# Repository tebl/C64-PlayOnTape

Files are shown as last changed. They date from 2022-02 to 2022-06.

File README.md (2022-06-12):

# C64 PlayOnTape
Remember waiting around for what sometimes would feel like forever, just to get your favourite game loaded from your trusty datasette? Well, now you can now attempt to return to a slightly less irritating version of those good old days - loading games'll take just as long as they did back then, just without the need to fiddle with the azimuth setting. Based on the rather excellent [tapuino](https://github.com/sweetlilmre/tapuino) project, there's even an accompanying [blog](http://sweetlilmre.blogspot.com/search/label/Tapuino) that included instructions on how to build one all by yourself.

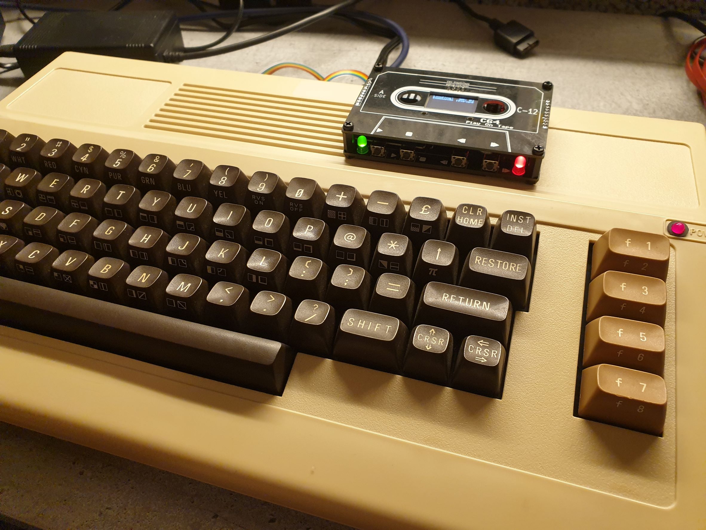
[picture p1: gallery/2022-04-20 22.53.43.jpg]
Finished unit with C64


Personally I haven't had much success building prototypes on breadboards, veroboard and almost every other option available within my severely limited cashflow. I highly suspect that part of this is due to my tendency for only buying the cheapest stuff around, so in order to keep myself sane I went straight from the blog onto designing the PCBs in KiCAD. On the plus side the files are here for anyone to enjoy, just remember that there's no warranty beyond my promise that it worked that one time I built one. If your C64 blows up due to problems assembling or using it, know that I'll be happy to take it off your hands for spare parts.

- [C64 PlayOnTape](#c64-playontape)
  - [1.1> Modules](#11-modules)
  - [1.2> Acknowledgements](#12-acknowledgements)

## 1.1> Modules
For the technical details as well as information regarding the modules included by this specific github project, consult the table below. Follow the documentation links for build instructions, BOM and anything else you'd for that specific module. Faceplates and any backplates listed are for the most most part only decorative, allowing you to put together something similar to a case without actually requiring a 3d-printer. Also, check out the [schematics](https://github.com/tebl/C64-PlayOnTape/tree/main/documentation/schematic) for more information about the electronic side of things.

| Module | Required | Documentation | Order |
| --- | --- | --- | --- |
| [C64 PlayOnTape Module](https://github.com/tebl/C64-PlayOnTape/tree/main/PlayOnTape%20Module) | Yes | [Documentation](https://github.com/tebl/C64-PlayOnTape/blob/main/PlayOnTape%20Module/README.md), [BOM](https://github.com/tebl/C64-PlayOnTape/blob/main/PlayOnTape%20Module/README.md#3-bom), [Getting started](https://github.com/tebl/C64-PlayOnTape/blob/main/documentation/getting_started.md) | [PCBWay](https://www.pcbway.com/project/shareproject/C64_PlayOnTape_7281e4c0.html)
| [C64 PlayOnTape Adapter](https://github.com/tebl/C64-PlayOnTape/tree/main/PlayOnTape%20Adapter) | Yes | [Documentation](https://github.com/tebl/C64-PlayOnTape/blob/main/PlayOnTape%20Adapter/README.md), [BOM](https://github.com/tebl/C64-PlayOnTape/blob/main/PlayOnTape%20Adapter/README.md#3-bom) | [PCBWay](https://www.pcbway.com/project/shareproject/C64_PlayOnTape_Adapter_6b7e3197.html)
| [PlayOnTape Backplate](https://github.com/tebl/C64-PlayOnTape/tree/main/faceplates/PlayOnTape%20Backplate) | No | [Documentation](https://github.com/tebl/C64-PlayOnTape/blob/main/faceplates/PlayOnTape%20Backplate/README.md) | [PCBWay](https://www.pcbway.com/project/shareproject/C64_PlayOnTape_Backplate_04d028fa.html)
| [PlayOnTape Faceplate (A1)](https://github.com/tebl/C64-PlayOnTape/tree/main/faceplates/PlayOnTape%20Faceplate%20A1) | Recommended | [Documentation](https://github.com/tebl/C64-PlayOnTape/blob/main/faceplates/PlayOnTape%20Faceplate%20A1/README.md), [BOM](https://github.com/tebl/C64-PlayOnTape/blob/main/faceplates/PlayOnTape%20Faceplate%20A1/README.md#3-bom) | [PCBWay](https://www.pcbway.com/project/shareproject/C64_PlayOnTape_Faceplate_FA1_dac67ded.html)

## 1.2> Acknowledgements
Everything comes from something, in particular when it comes to most of my electronics projects. I mainly build things I would like to own, often doing a respin to fit my own particular style and preferences with most of the hardest parts of the designs already provided by people more knowledgable than I. As already mentioned, my designs are based on the rather excellent [tapuino](https://github.com/sweetlilmre/tapuino) project with a new name just to keep things separate, for more details on how it functions - check out his accompanying [blog](http://sweetlilmre.blogspot.com/search/label/Tapuino) as well.

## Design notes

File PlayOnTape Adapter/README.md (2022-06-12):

# PlayOnTape Adapter
Originally I designed the [C64 PlayOnTape](https://github.com/tebl/C64-PlayOnTape) with the idea that I would simply solder the cable straight to a connector and call it a day, but then I remembered that I've always loathed soldering cables thought that might be a case of having both too many and too few thumbs depending on the situation. The following revision was therefore redesigned with this little adapter board, so that the two can be connected using a commonly sold 2x3 pin IDC flat ribbon cable (usually sold as a *"6pin IDC JTAG ISP"*-cable on ebay and similar sites).

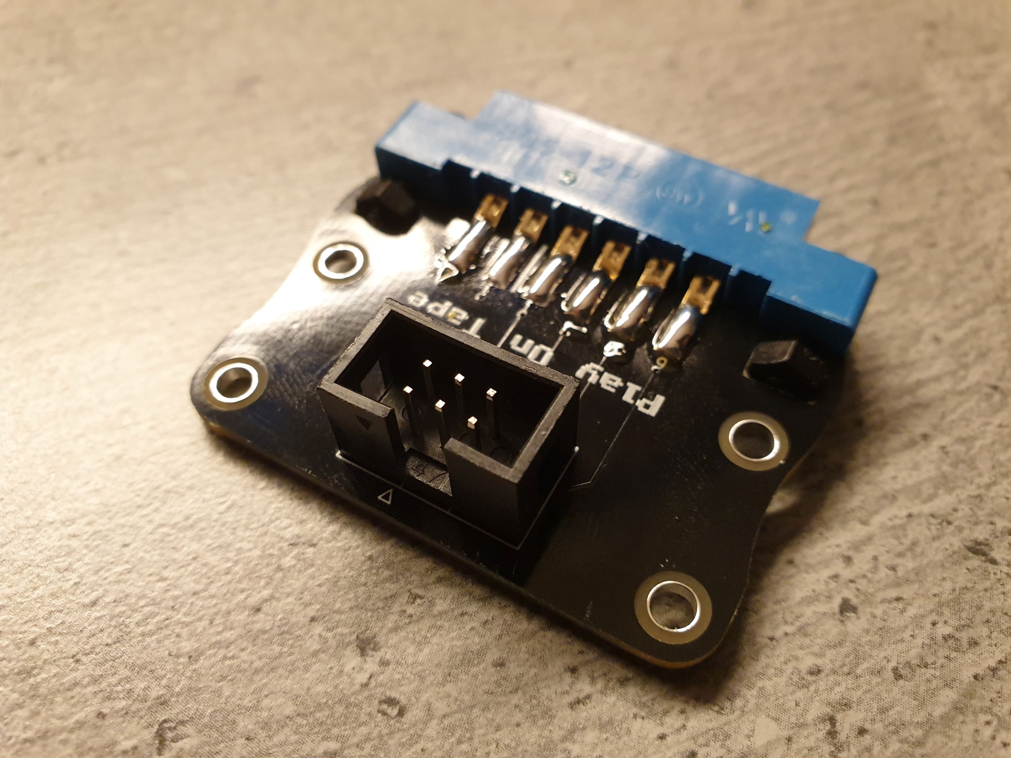
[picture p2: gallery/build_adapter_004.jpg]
Completed unit


- [PlayOnTape Adapter](#playontape-adapter)
  - [1> Building the module](#1-building-the-module)
  - [2> Schematic](#2-schematic)
  - [3> BOM](#3-bom)

## 1> Building the module
Start by checking out the [BOM](#3-bom) and verify that you have the components needed before continuing, it's beyond frustrating to realize you need just that single item before being able to complete the build - with shipping times from China being what they are, it's better to get it right the first time. Personally I find that if it's very cheap, I'll just order several different ones - just in case one gets delayed or lost somewhere.

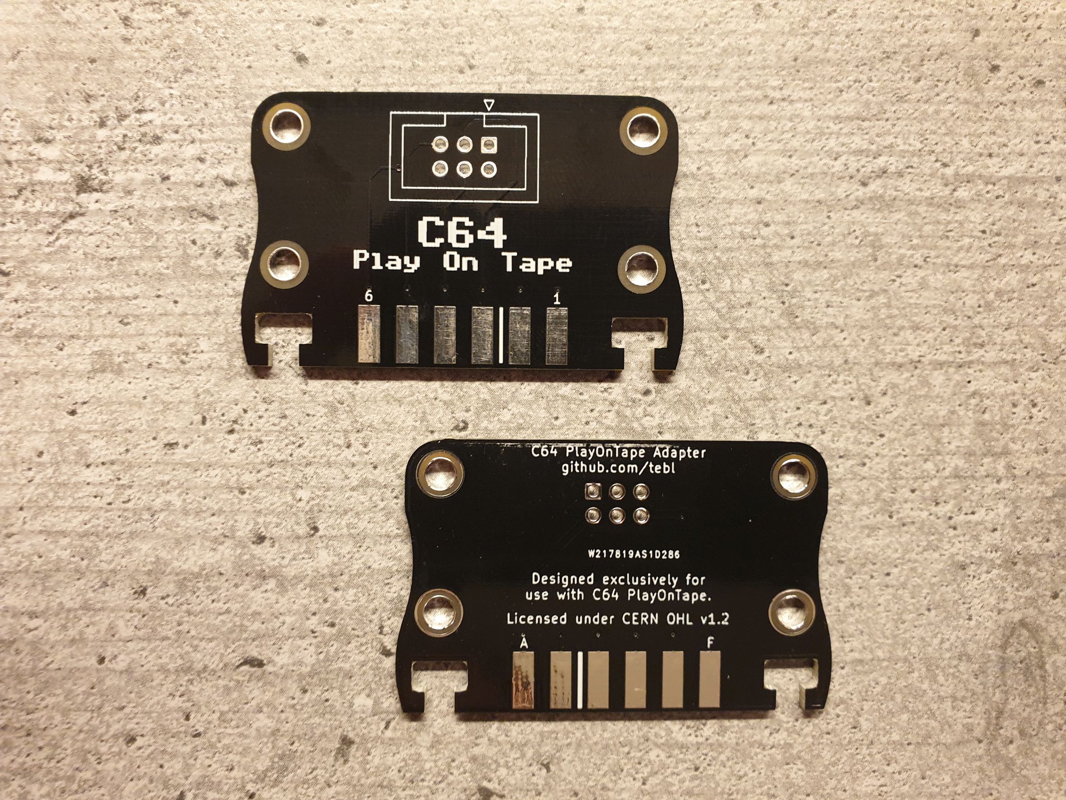
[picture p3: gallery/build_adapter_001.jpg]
Build 001


Starting by doing a visual inspection of the PCB, familiarize yourself with the placement of components as ordered - in particular, which side of the board that the components themselves should be soldered. Towards the sides there is a slot for holding a couple of M3-nuts, this is used to keep the connector from breaking away due to handling.

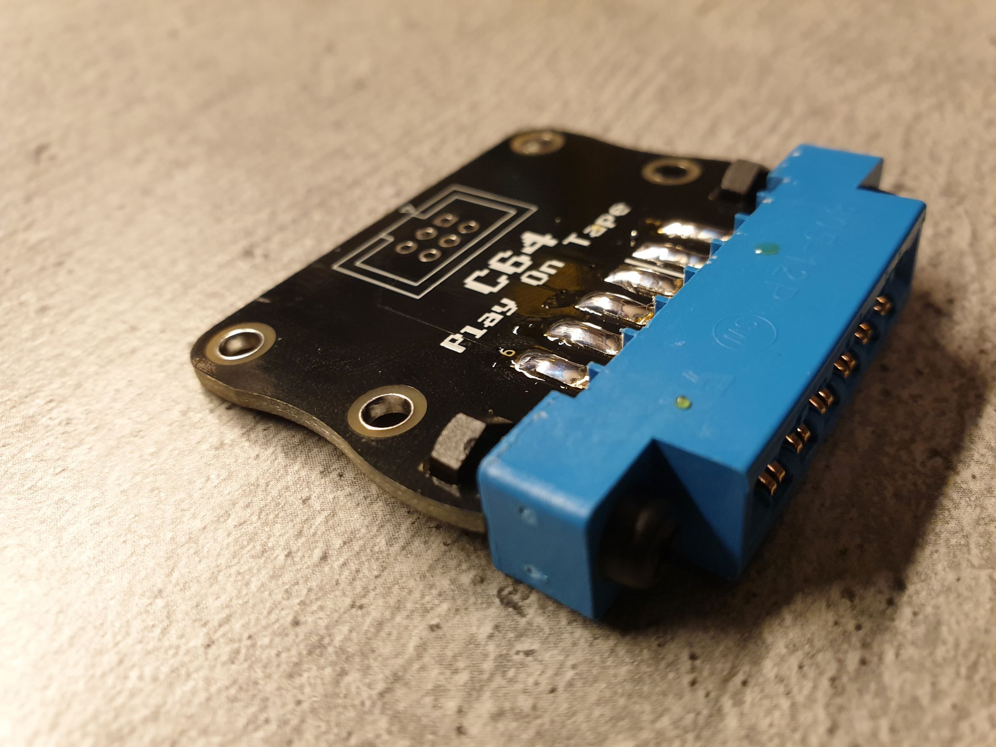
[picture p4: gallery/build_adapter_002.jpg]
Build 002


The 805-series connector comes in two variants, one with wider contacts that can have wires soldered to them and the more narrow pins intended for inserting into and soldering onto a PCB. We're - almost - not doing any of that, so either variant will be fine. Instead we will be soldering it an angle onto the side of the PCB as shown above, but since we want it to be a somewhat mechanically good connection we'll start by attaching it using the nylon M3-nuts and screws. The nuts'll only fit in the way that is shown, for the screws we'll just screw it through the connector and into the nut (cutting down the length of the screws as needed).

When the screws are fitted into place, it should hold the connector well enough that we can look into soldering it into place. At this point you'll usually have the pins hovering somewhat over the PCB, this is easily rectified by using the flat edge of a screwdriver to push each of them at angle so that they align with the pads below. Then, we just solder each of the pins into place, using plenty of solder to give it some added support.

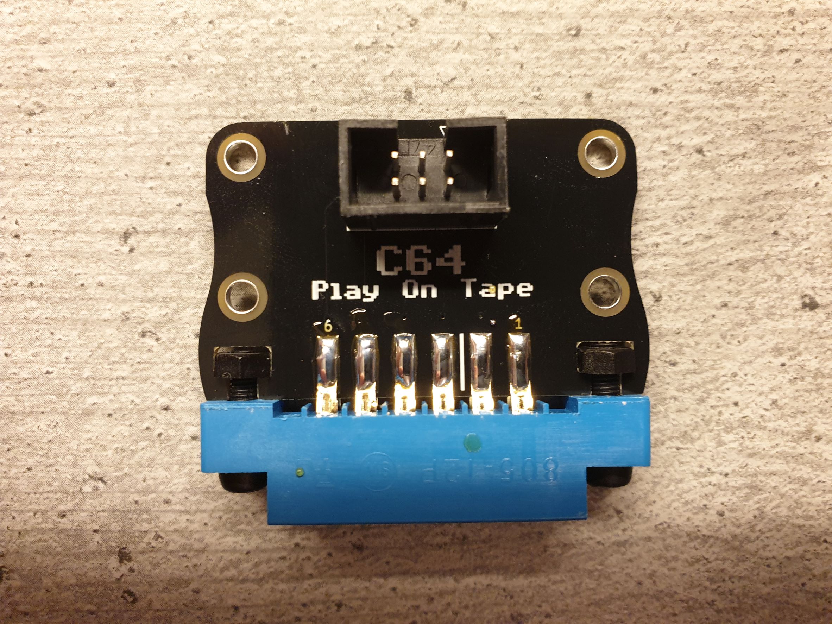
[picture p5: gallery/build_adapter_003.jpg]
Build 002


The last part is just adding the 2x3 pin IDC male straight socket, ensuring that the keying ends up in the correct orientation. At the bottom between some of the 805-series connector pins there is also a white line, this should match the keying one would expect to be used with the Commodore 64s cassette port. I don't think there's anything sold that would work, but you can easily make it from a piece of plastic by following a video by [Hey Birt!](https://www.youtube.com/c/HeyBirt) on the topic of [stupid proofing your edge connectors](https://www.youtube.com/watch?v=vWt5WGZH8hI).

# 2> Schematic
The supplied KiCad files should be sufficient as both a schematic and as a  starting point for ordering PCBs (basically you could just zip the contents of the export folder and upload that on a fabrication site), the schematic is also available in [PDF-format](https://github.com/tebl/C64-PlayOnTape/tree/main/documentation/schematic) found within the schematics-part of the [documentation](https://github.com/tebl/C64-PlayOnTape/tree/main/documentation).

# 3> BOM
Most parts should be easy to get a hold of from your favourite local electronic component shop, but given that I don't have access to such shops where I live so everything was based on whatever I could get cheapest from eBay/AliExpress (free shipping, plan on waiting 3-4 weeks for delivery though). If you are in doubt what to order from a high-end electronics parts provider, I recommend that you study the pictures as the more common Chinese parts may be harder to find in the myriad of options presented there.

| Reference | Item | Count | Order |
| --- | --- | ----- | ----- |
| PCB | Fabricate using Gerber files | 1 | [PCBWay](https://www.pcbway.com/project/shareproject/C64_PlayOnTape_Adapter_6b7e3197.html)
| J1 * | 2x3 pin straight male IDC-socket | 1 |
| J2 | 12-pin 805-series 3.96mm card edge connector | 1 |
| Cable | 6-pin IDC cable | 1 |

*) This could be replaced by standard male pin headers if you wanted to, but using the keyed IDC-connector is recommended in order to avoid accidents.

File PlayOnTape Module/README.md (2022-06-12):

# PlayOnTape Module
Remember waiting around for what sometimes would feel like forever, just to get your favourite game loaded from your trusty datasette? Well, now you can now attempt to return to a slightly less irritating version of those good old days - loading games'll take just as long as they did back then, just without the need to fiddle with the azimuth setting. Based on the rather excellent [tapuino](https://github.com/sweetlilmre/tapuino) project, there's even an accompanying [blog](http://sweetlilmre.blogspot.com/search/label/Tapuino) that included instructions on how to build one all by yourself.

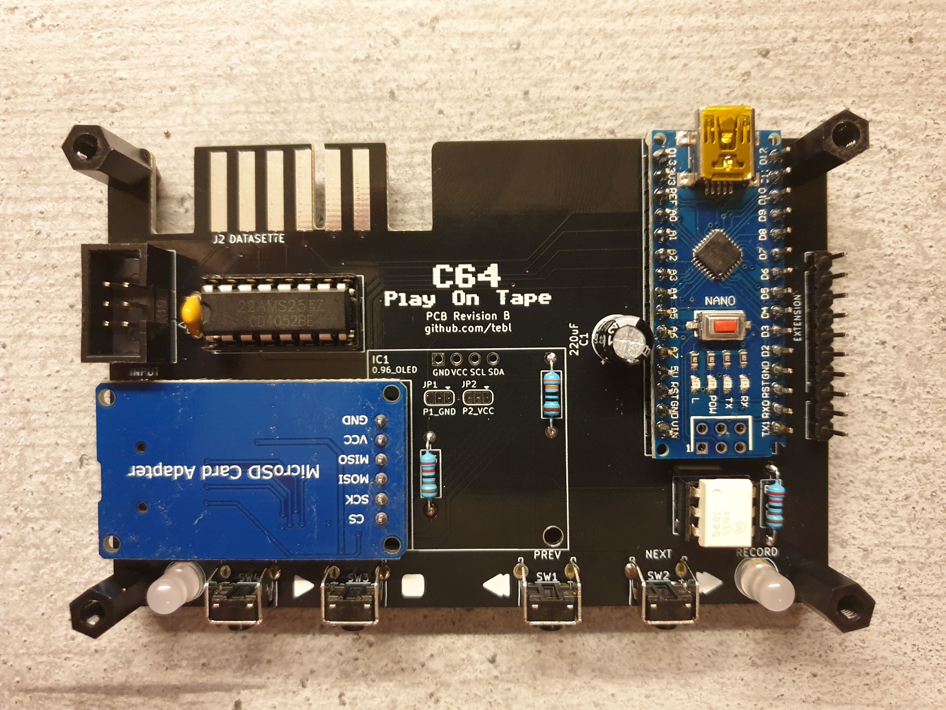
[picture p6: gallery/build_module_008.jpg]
Completed unit


This is the main module, containing most if not all of the electronic circuit needed to make it all work as expected. By most, I mean that even though you can install the display directly on this module in order to build a minimal option, I would expect you to install the display on one of the [faceplates](https://github.com/tebl/C64-PlayOnTape/tree/main/faceplates). You will also need the [cable adapter](https://github.com/tebl/C64-PlayOnTape/tree/main/PlayOnTape%20Adapter) so that you have some way of connecting it to your Commodore 64, via a 6-pin IDC-cable.

- [PlayOnTape Module](#playontape-module)
  - [1> Building the module](#1-building-the-module)
    - [1.1> Installing the display](#11-installing-the-display) 
    - [1.2> Installing the firmware](#12-installing-the-firmware)
    - [1.3> Finishing steps](#13-finishing-steps)
  - [2> Schematic](#2-schematic)
  - [3> BOM](#3-bom)

# 1> Building the module
Start by checking out the [BOM](#3-bom) and verify that you have the components needed before continuing, it's beyond frustrating to realize you need just that single item before being able to complete the build - with shipping times from China being what they are, it's better to get it right the first time. Personally I find that if it's very cheap, I'll just order several different ones - just in case one gets delayed or lost somewhere.

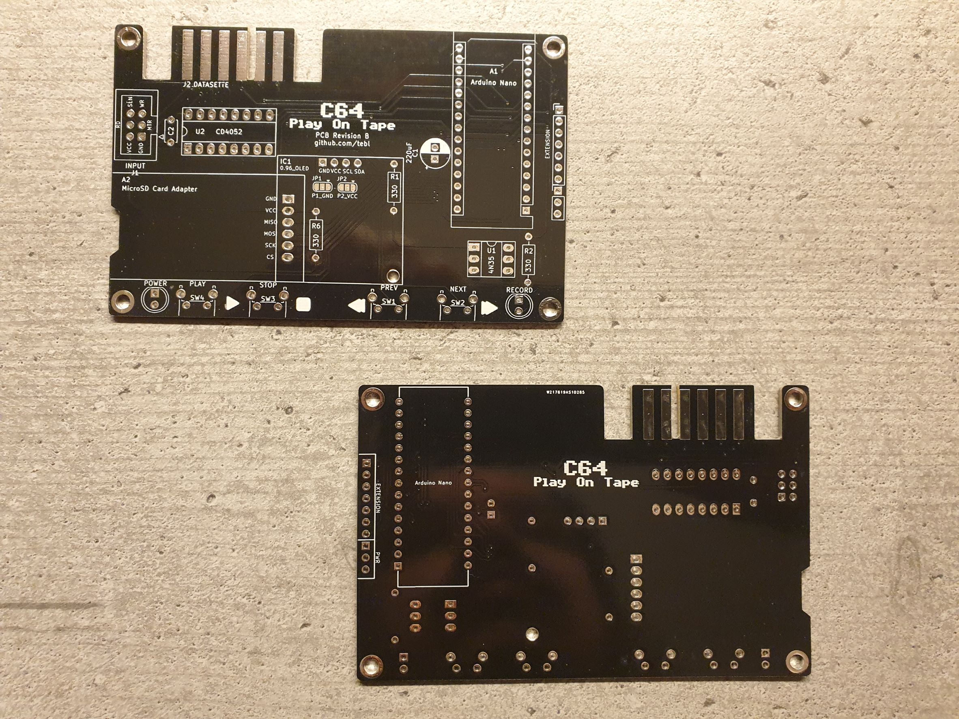
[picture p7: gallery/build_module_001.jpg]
Build 001


Starting by doing a visual inspection of the PCB, familiarize yourself with the placement of components as ordered some time ago. This time, focusing in particular on determining on which side of the board that the components themselves should be soldered and their respective orientation.

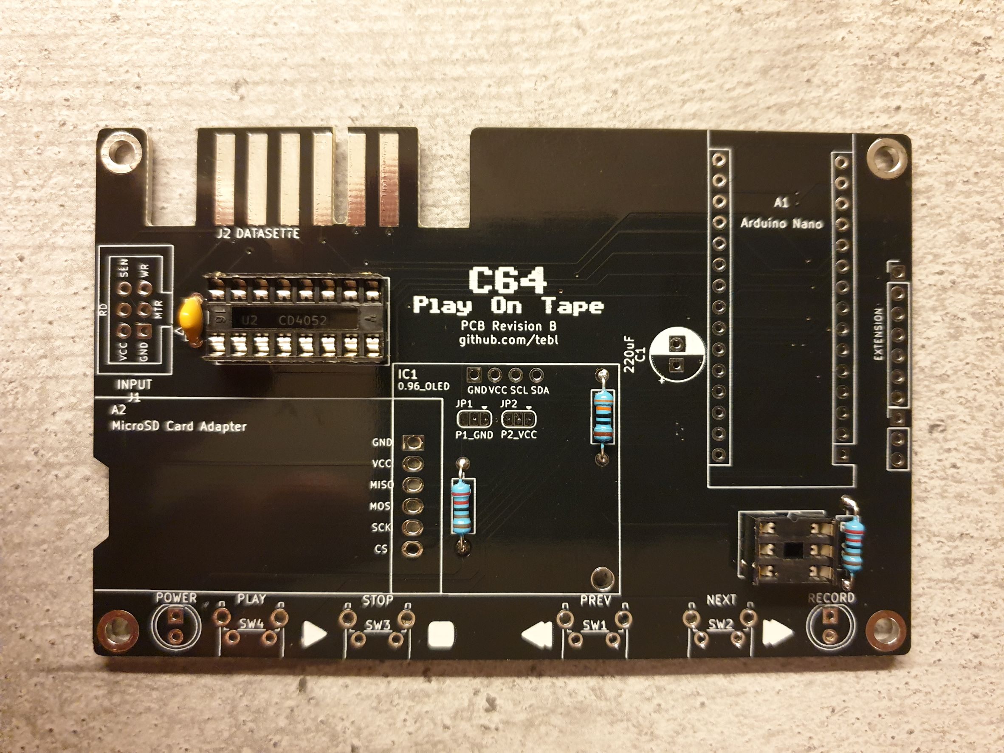
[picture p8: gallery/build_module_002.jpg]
Build 002


As with all builds of this type we'll start by installing the smallest components first, usually going by the height of the components when sitting flush against the board. A good starting point will therefore be the three resistors, but because things are never all that easy - we'll need to pick a potentially more suitable value for R2 and R6. The reason for this is that the value needed would depend on the type of LEDs you are using, the common cheap coloured LEDs will work with this value as long as you resist the temptation to pick *blue* as any of the colours.

The more modern bright or even just clear LEDs have a significantly higher efficiency, meaning that they would likely burn out or simply remain uncomfortably bright at such a low resistor value! The textbook way of handling this kind of issue is reading the datasheet for your LEDs, noting down forward voltage drop and then calculating the proper value to use. Yeah, I'm not doing that either! Your other options are therefore to simply choose a safe value somewhere between 1k and 3k3 (depending on your preferences), try it out on a breadboard or hold off on this until the rest of the unit has been built up and can be powered. If you chose the latter, then you'd just carefully take aim and jam a resistor in there, hold it into place and see if it looks good to you.

Adding the single non-polarized capacitor is the next likely candidate, as a 100nF capacitor it would normally have the number *"104"* printed on it. I've also taken the time to install any sockets needed, mostly because they are cheap and it allows me to easily ~~steal~~ borrow the ICs for some later project - just make sure to line up the little indent marking the side with pin 1 so that it matches what is printed on the PCB itself.

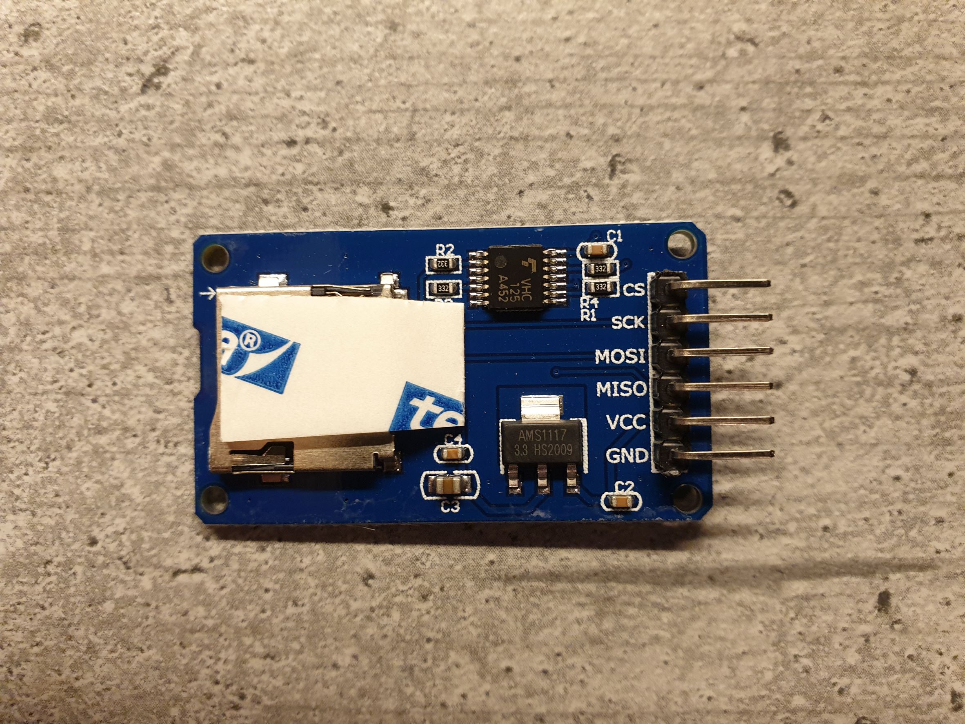
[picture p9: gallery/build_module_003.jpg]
Build 003

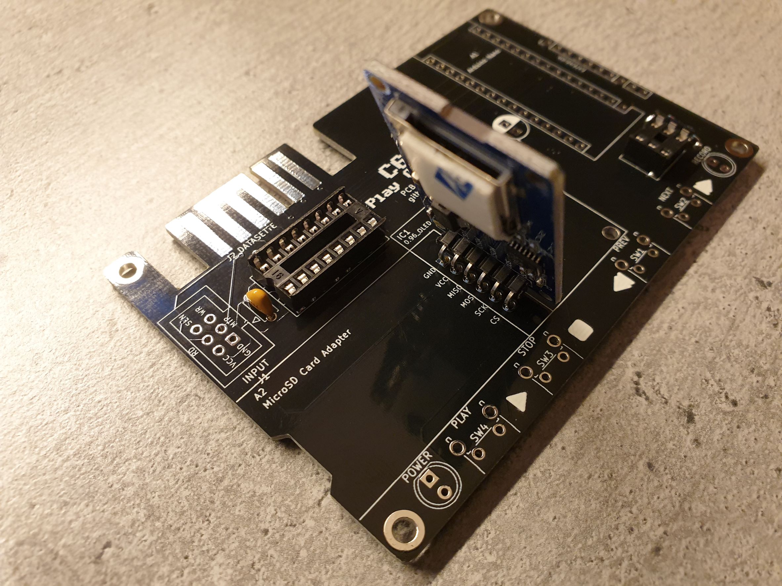
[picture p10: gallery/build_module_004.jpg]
Build 004

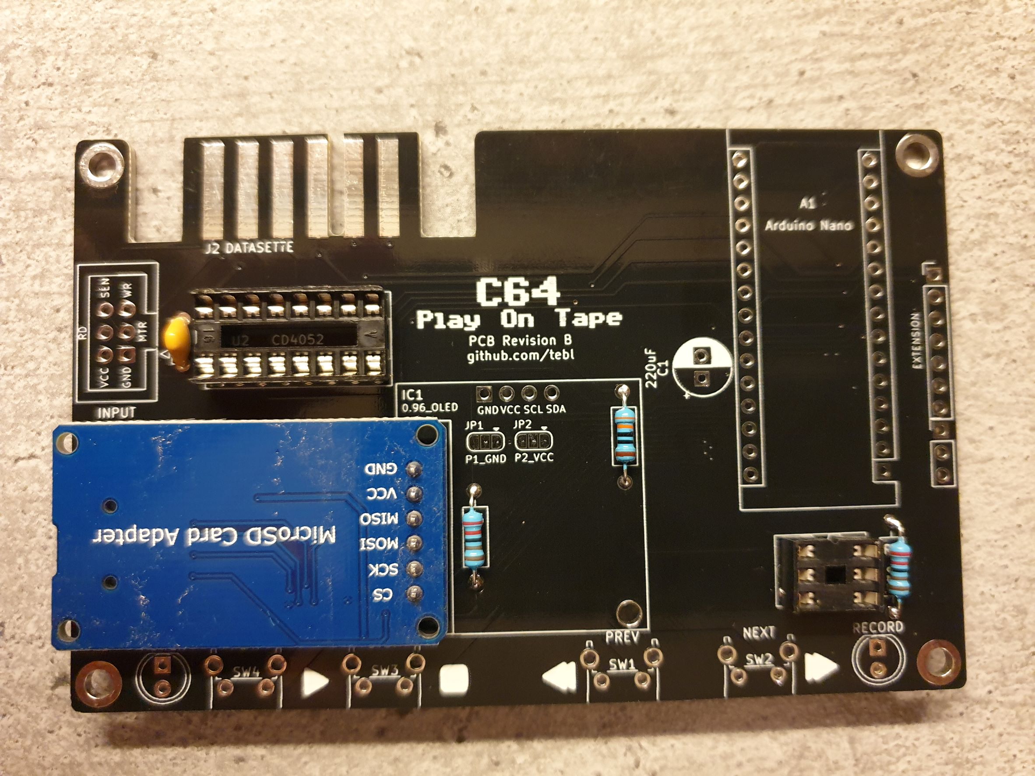
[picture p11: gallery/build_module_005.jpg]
Build 005


Installing the *MicroSD Card Adapter* is easy as long as a few easy steps are followed, mostly just as shown in the images above. First we'll attach a bit of thick double-sided tape, often referenced to as mounting tape, to the top of the adapter MicroSD slot on the adapter. Just take care to leave enough room so that it does not cover up the little latches on the sides of the metal slot. When satisfied insert the pins into the holes, remove the backing on the tape and bend the module over so it ends up sitting flush against the board. Finish up by soldering the pins from the underside, then using trim the excess of the pins using a sturdy set of side-cutting pliers. Touch up the solder points afterwards, just to ensure that we didn't crack any of the joints when doing the cutting.

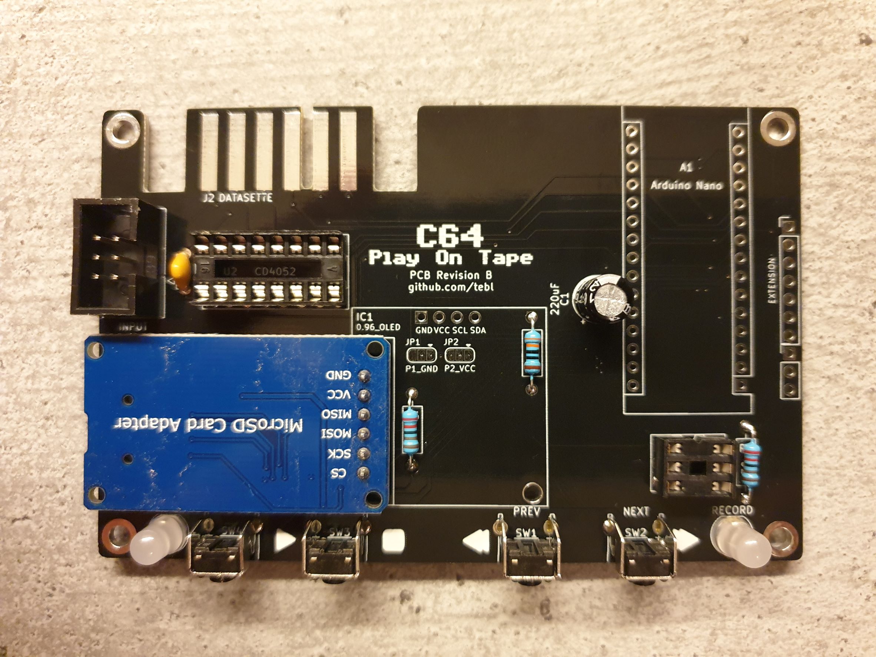
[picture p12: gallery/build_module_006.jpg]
Build 006


Continuing on with the build process, we've added the 6-pin male straight IDC-connector - ensuring that we get the keying in the correct place - followed by adding the switches need to control the device. The LEDs we've already mentioned earlier, but here we've finally gotten to the point of actually installing them - ensuring that the longer pin goes into the round hole.

The board also features a single electrolytic capacitor that we should probably find a place for, this component has a polarity that we need to pay attention to. The line on the component needs to be matched up with the filled in area on the footprint, this will also match up the longer leg with the side marked with a tiny *"+"*. While the circuit doesn't require a specific voltage rating, I recommend using a 16v component as the higher rated parts will be physically larger and taller (causing problems with fitting it under the faceplate). 

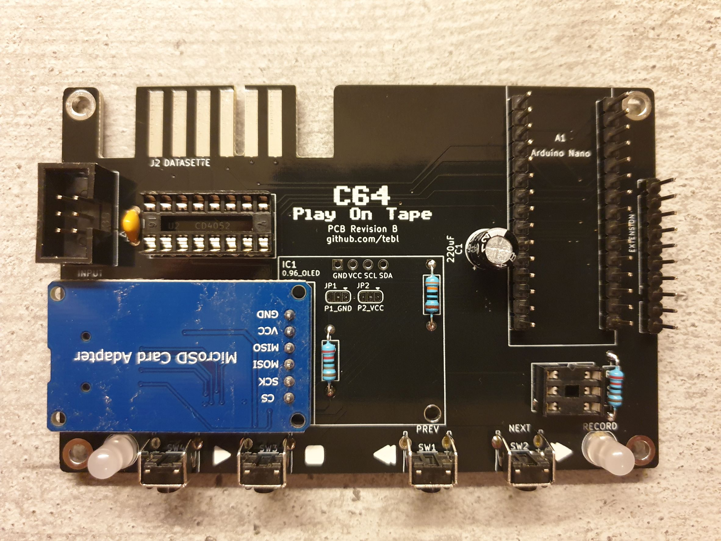
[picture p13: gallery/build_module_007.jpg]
Build 007


The Arduino Nano is attached to the board using standard male pin-headers, these need to be soldered in somewhat straight - or - you may encounter soldering in the Arduino itself. The pin headers on the far-right have also been added, these are used to connect the signals required by the faceplate. 

**NB!** If you have a relatively high expectation in regards to the quality of your components, then there is the option of constructing a device that is slightly thinner. The process is simply to install 8mm hex standoffs, trimming the tops of the Arduino pins, then soldering the longer variety of the pin headers for the right-most pins directly to the faceplate instead of making it detachable (you may need to use longer pin headers or a small section of ribbon cable). Understandably enough, you'd hold off on doing this until every other component has been fitted.

Build 008

The Arduino is then inserted onto the pins, then soldered into place though experience should tell us that we should at least test the device before soldering it onto a board - an easy enough test is to simply check that we are able to compile and upload a *blink*-sketch to it beforehand. The remaining ICs are then inserted into the sockets, ensuring that the indent, or dot in the case of the 4N35, is matched up with the indent found on the sockets.

As you will no doubt intend to use this module with a faceplate, we'll need to add some M3x10mm nylon hex standoffs to the mounting holes on the far corners of the board. Add a set of M3 nylon hex nuts on the bottom as needed with F-M standoffs, M3 nylon screws when used with F-F hex standoffs instead. This is also a suitable time to take a detour, mainly by building your [faceplate](https://github.com/tebl/C64-PlayOnTape/tree/main/faceplates) of choice then jump to [1.2> Installing firmware](#12-installing-firmware) once that's been completed and installed.

## 1.1> Installing the display
Skip this section if you chose to install the display on a [faceplate](https://github.com/tebl/C64-PlayOnTape/tree/main/faceplates), instead choosing to build a slightly cheaper version of the device. Unfortunately there are several versions of the 128x64 I2C displays, some will have a different physical sizes though they'd look the same at the first glance. Two different displays are shown on the image below.

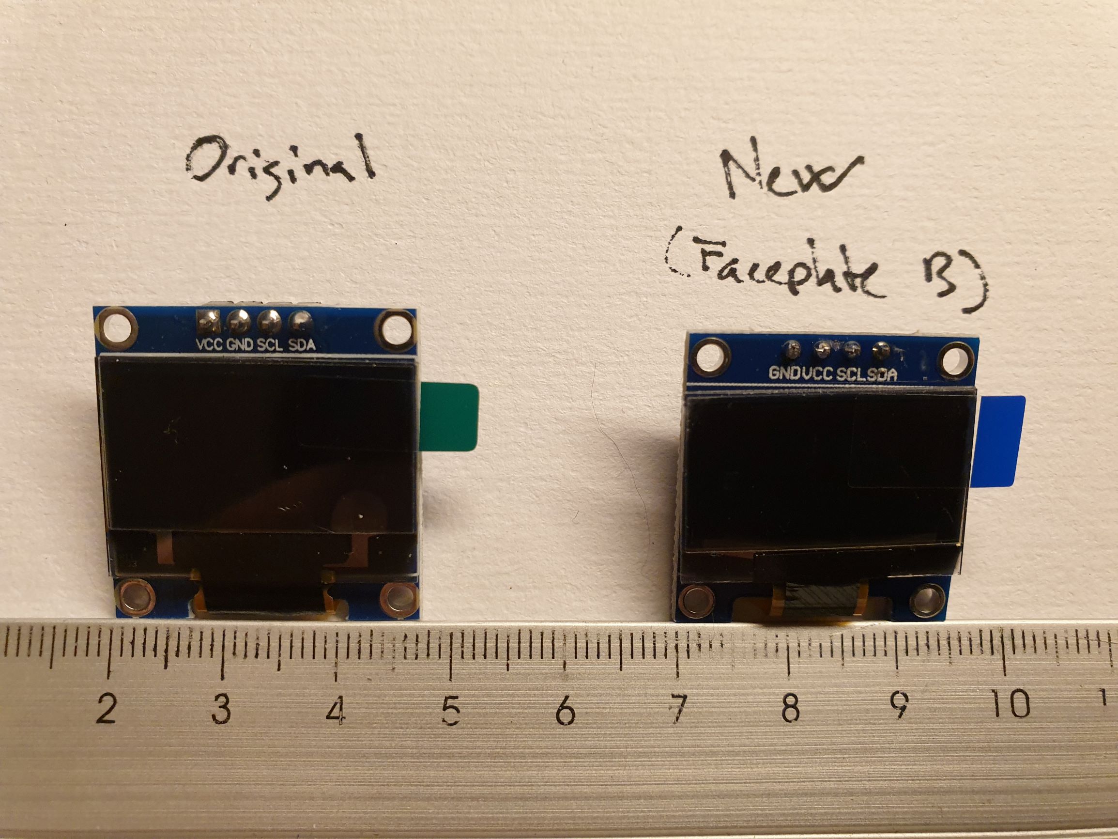
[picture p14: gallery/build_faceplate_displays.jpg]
Build 008


When used without a faceplate, both of these will work the same when installed onto the PCB-module - however, there is one **MAJOR DIFFERENCE** that we need to pay attentions to, and that is the fact that some versions of these displays will have their power pins swapped! We'll need to wire them up according to the display we have, this is done by linking JP1 and JP2 to account for this: looking at your display, if the first pin on your display is labelled as *GND* then you will need to link both of these across pins *1-2* (the little triangle denotes pin 1). If on the other hand, the first pin is labelled as *VCC* then we need to link pins *2-3*. 

Given the need for the display to clear the *MicroSD Card Adapter* already soldered to the board, I suggest soldering some female pin headers to the board and insert the display onto those pin headers. If you require some mechanical support to the display, you can install a M2 nylon hex standoff to the right side of the display (the mounting hole on the board will only align with the *original*-type of display shown earlier) 

## 1.2> Installing the firmware
Installing, or updating for that matter, the firmware is accomplished through the [Arduino IDE](https://www.arduino.cc/en/software). Start by downloading a copy of the sketch supplied by its original author, it's on [github](https://github.com/sweetlilmre/tapuino) and can simply click the green *Code*-button and then select *Download ZIP*. Extract somewhere that you'll be able to locate at a later point in time.

Within the directory of files you just extracted, remembering how I just seconds ago to you to put it somewhere that you'd be able to locate them again? All good? Cracking on then. Start by renaming the file called *config-user.h.example* to *config-user.h*, depending on your choice of operating system you may need to explicitly tell it to actually show you the extensions for the file. Why Microsoft constantly chooses to make things more difficult? I'll probably never know.

Editing the contents of the file we just renamed, now properly named *config-user.h*, we'll need to uncomment the lines specifying the type of display that we'll be using. Given that I've already forced you to use a 128x64 I2C OLED display, the lines relevant to us  are the following (in addition to specifying the language to use):
```
#define LCD_USE_SSD1306_OLED_MODULE
#define LCD_I2C_ADDR        0x3C // I2C address for the OLED
#define LCD_SSD1306_128x64

#define TAPUINO_LANGUAGE_EN
```

Opening up the Arduino sketch named *tapuino.ino* in the Arduino IDE, we'll need to start by configuring the type of Arduino we'll be using - specifying the *Arduino Nano* as your board.

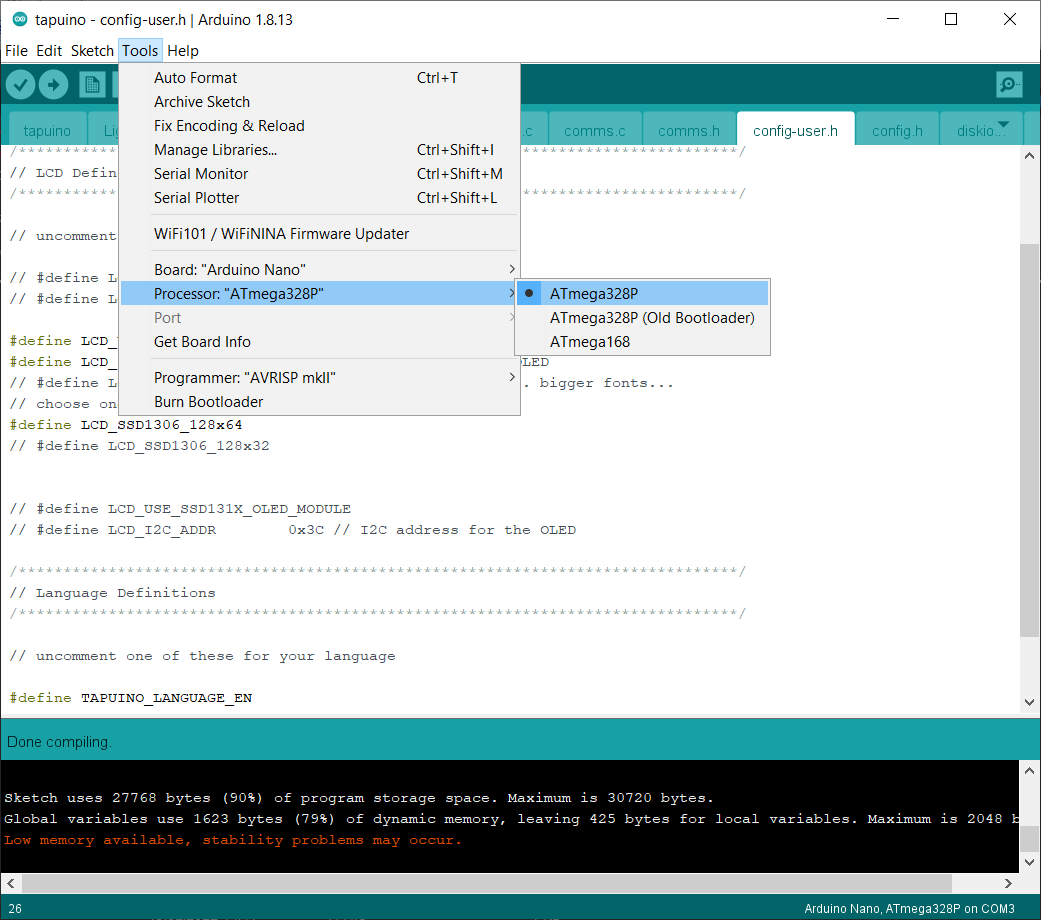
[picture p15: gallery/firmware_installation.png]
Arduino settings


With the board connected to your computer using a USB-cable, select the *port* provided by it (ideally you'll only have one option here, depending on whatever else you've got connected up to your system). At this point you should probably just attempt to verify and upload the sketch to your Arduino, in some cases the upload may end up looking like it got stuck until finally timing out a few minutes later. If that is the case, you may have the older version of the bootloader on your *Arduino Nano* and therefore you may need to select *ATmega328P (Old Bootloader)* from the *Processor* menu and try again.

If all goes well, your *C64 PlayOnTape* should initialize the display and potentially give you an error stating that it failed to initialize - this just means that an SD-card has not been inserted into the slot (remember that since we installed the upside down, we need to insert the card upside down as well). Detach the USB-cable and set it aside, we won't be needing that anymore.

**NB!** The *C64 PlayOnTape* should not be connected to your computer via the USB-cable when used with a Commodore 64. You might kill your Commodore 64, you might kill your laptop - so it is probably best not to.

## 1.3> Finishing steps
The last steps as should be expected is adding some screws on top to hold the faceplate firmly in place, connect it to the cable adapter using a 6-pin IDC cable and then connect it to you Commodore 64 with everything else powered off. With an SD-card inserted with some TAP-files ready to go, you can just select one and get to using it.

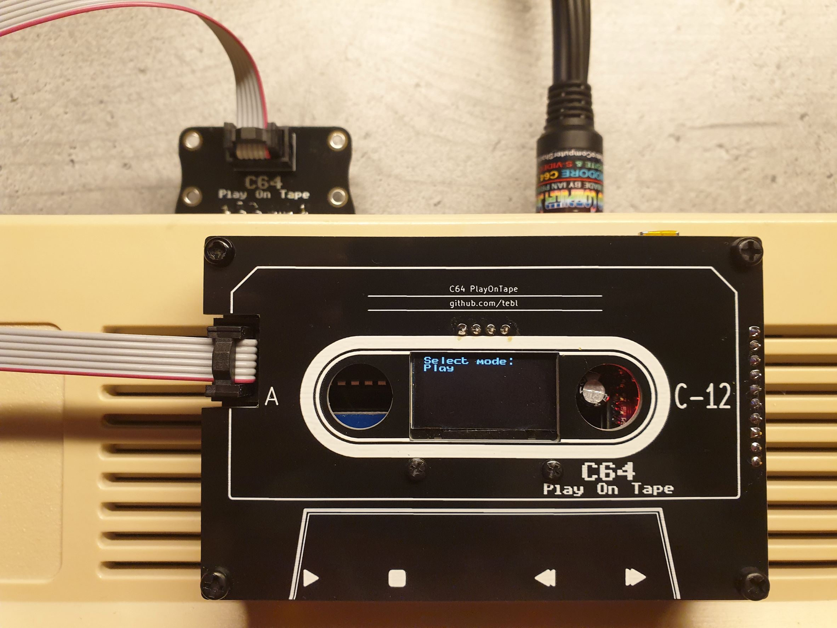
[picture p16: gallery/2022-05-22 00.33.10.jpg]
Getting started


A simple guide on [getting started](https://github.com/tebl/C64-PlayOnTape/blob/main/documentation/getting_started.md) have been put together in order to cover this in slightly greater detail, check it out if you need a refresher on topics not already covered.

# 2> Schematic
The supplied KiCad files should be sufficient as both a schematic and as a  starting point for ordering PCBs (basically you could just zip the contents of the export folder and upload that on a fabrication site), the schematic is also available in [PDF-format](https://github.com/tebl/C64-PlayOnTape/tree/main/documentation/schematic) found within the schematics-part of the [documentation](https://github.com/tebl/C64-PlayOnTape/tree/main/documentation).

# 3> BOM
Most parts should be easy to get a hold of from your favourite local electronic component shop, but given that I don't have access to such shops where I live so everything was based on whatever I could get cheapest from eBay/AliExpress (free shipping, plan on waiting 3-4 weeks for delivery though). If you are in doubt what to order from a high-end electronics parts provider, I recommend that you study the pictures as the more common Chinese parts may be harder to find in the myriad of options presented there.

| Reference | Item | Count | Order |
| --- | --- | ----- | ----- |
| PCB | Fabricate using Gerber files | 1 | [PCBWay](https://www.pcbway.com/project/shareproject/C64_PlayOnTape_7281e4c0.html)
| A1 | Arduino Nano (ATMega328) | 1 |
| A2 | MicroSD Card Adapter | 1 |
| C1 | 220uF electrolytic capacitor (6.3mm x 2.5mm) | 1 |
| C2 | 100nF ceramic capacitor (5mm) | 1 |
| D1,D2 | 5mm LEDs, preferably bright clear variety | (2)|
| IC1 | 128x64 I2C OLED display | (1)|
| J1 * | 2x3 pin straight male IDC-socket | 1 |
| J3 | 7-pin male straight pin header | 1 |
| J5 | 3-pin male straight pin header | 1 |
| R1 | 330 ohm resistor | 1 |
| R2,R6 ** | 330 ohm resistor | (2)|
| SW1-SW4 | 6x6x5mm right-angle momentary button | 4 |
| U1 | 4N35 optocoupler (DIP-6) | 1 |
| U2 | CD4052 (DIP-16) | 1 |
| Cable | 6-pin IDC cable | 1 |
| Mounting *** | Nylon M3 hex standoffs 10mm (M-F) | 4 |
| Mounting *** | Nylon M3 nylon nuts | 4 |
| Mounting *** | Nylon M3x6mm nylon screws | 4 |

*) This could be replaced by standard male pin headers if you wanted to, but using the keyed IDC-connector is recommended in order to avoid accidents.
**) Resistor needs to have a value suitable for use with the type of LED installed. For modern bright LEDs consider using a value from 1k to 3k3 to avoid being completely blinded, better yet - check the datasheet and do the math.
***) These are used in various places of the project, these are available in the form of kits usually advertised *M3 nylon standoff kit* which should contain most of what you'd need.

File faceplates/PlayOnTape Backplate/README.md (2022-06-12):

# PlayOnTape Backplate

The backplate is mainly just a piece of PCB intended to cover up the underside of the module, this way the user does not necessarily have to feel like they're handling exposed electronics. For the most part the most voltage going through the thing is 9 volt so the risk is low, but I find it safer this way since I don't have to worry about the surface I'm placing it on (a few vintage computers have metal cases).

Backplate

# 1> Schematic
The supplied KiCad files should be sufficient as both a schematic and as a  starting point for ordering PCBs (basically you could just zip the contents of the export folder and upload that on a fabrication site), the schematic is also available in [PDF-format](https://github.com/tebl/8BIT-Wave/tree/master/documentation/schematic) found within the schematics-part of the [documentation](https://github.com/tebl/8BIT-Wave/tree/master/documentation).

# 2> BOM
Most parts should be easy to get a hold of from your favourite local electronic component shop, but given that I don't have access to such shops where I live so everything was based on whatever I could get cheapest from eBay/AliExpress (free shipping, plan on waiting 3-4 weeks for delivery though).

| Reference | Item | Count | Order |
| --- | --- | ----- | ----- |
| PCB | Fabricate using Gerber files | (1)| [PCBWay](https://www.pcbway.com/project/shareproject/C64_PlayOnTape_Backplate_04d028fa.html)

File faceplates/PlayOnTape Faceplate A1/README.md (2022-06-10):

# PlayOnTape Faceplate (A1)
The faceplate doesn't do all that much except making it look *"really really cool"*, to quote a *"really really cool"* comedy about male supermodels (Zoolander by the way, please don't judge my sense of humour)! To be perfectly honest you could actually do without the thing entirely, as the OLED-display could potentially be installed on the main module instead - however, what would the fun be in building a unit that'd be considerably less than what it was supposed to be? I'll leave that bit of decision-making up to you.

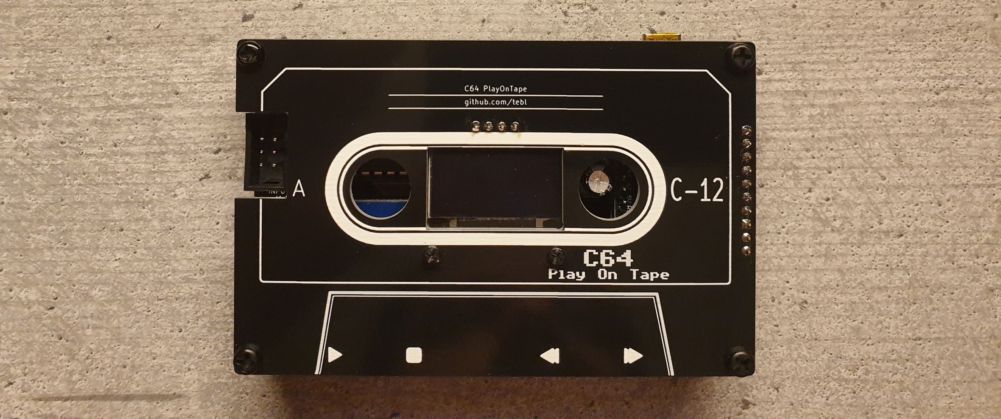
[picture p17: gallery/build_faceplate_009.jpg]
Completed unit


- [PlayOnTape Faceplate (A1)](#playontape-faceplate-a1)
  - [1> Building the module](#1-building-the-module)
  - [2> Schematic](#2-schematic)
  - [3> BOM](#3-bom)

## 1> Building the module
Start by checking out the [BOM](#3-bom) and verify that you have the components needed before continuing, it's beyond frustrating to realize you need just that single item before being able to complete the build - with shipping times from China as they are, better to get it right the first time (if it's very cheap I tend to order several just in case one gets delayed somewhere).

Before soldering anything together, you need to first determine which variation of the 128x64 SSD1306 OLED-display (0.96") you actually have - there is the **original** as designed for by this faceplate and there is the **new** version. The difference between the two is best spotted by looking at that the ribbon cable at the bottom display, the newer models models have a more narrow ribbon here as well as physical differences that's not as easy to spot from a picture on a listing. The two are functionally identical, but you need the original model as it is the version that fits properly with this specific faceplate.

OLED-display variations

The actual display usually comes with pin headers already installed, which is unfortunate as they are on the wrong side - refer to the pictures below to see how it is meant to fit into the mounting. You could always try desoldering the pins, but I've found that this is a rather cumbersome step - even with a desoldering station. The easiest solution however, is to melt the solder on a single pin using your soldering iron, then pushing the pin through the PCB using something metal like a pair of pliers. Please remember: heated metal burns, quite a bit to be honest!

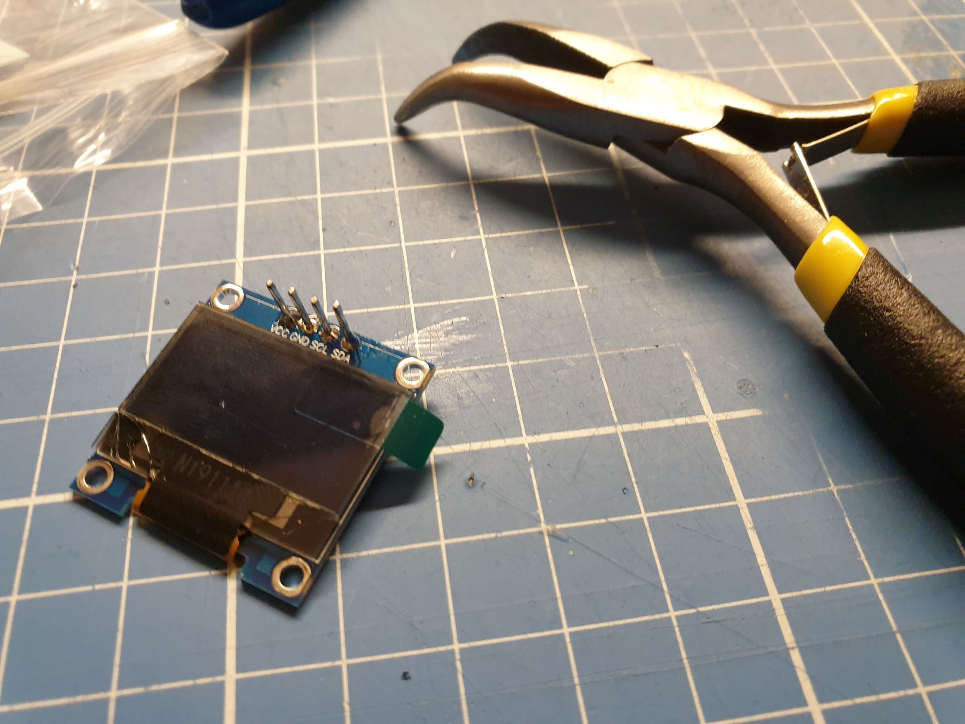
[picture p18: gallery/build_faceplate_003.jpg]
Push pins through


If you've used the method of just pushing the pins through, then you should have a result as shown above - this is then almost ready for soldering into place, but we won't do that just yet. There are some things you must know before that.

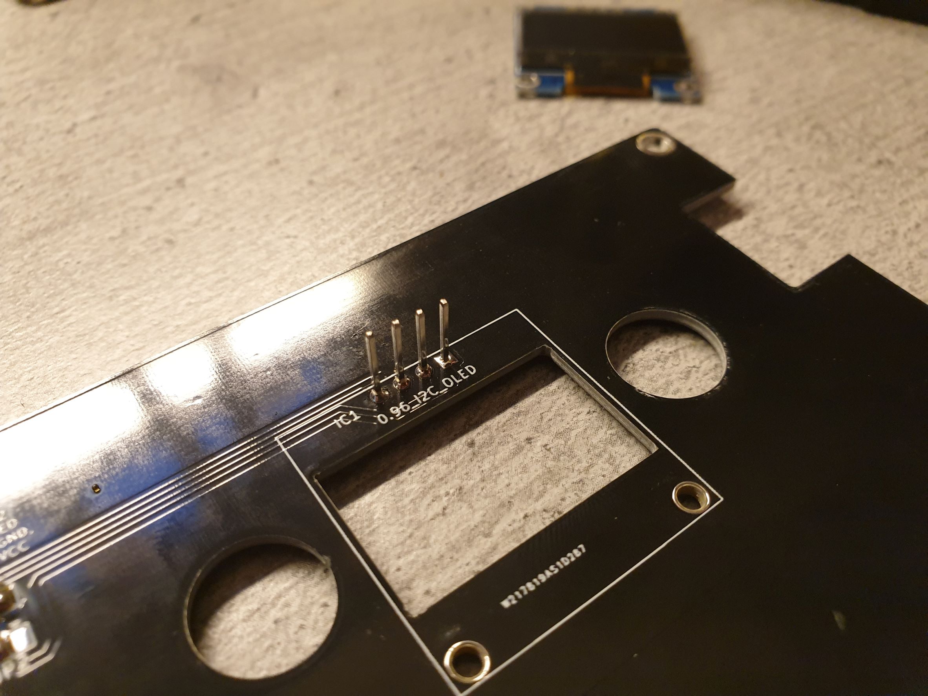
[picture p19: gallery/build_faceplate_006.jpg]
Removed plastic part


If you went the route of desoldering the pin headers then just go ahead and add some new ones to the bottom of the faceplate and solder from the front of the board. The final step then is to find the pair of pliers you've already narrowly avoided using, to pull off the plastic bit from the pins we just soldered in. The result you're left with should look something like what is shown above.

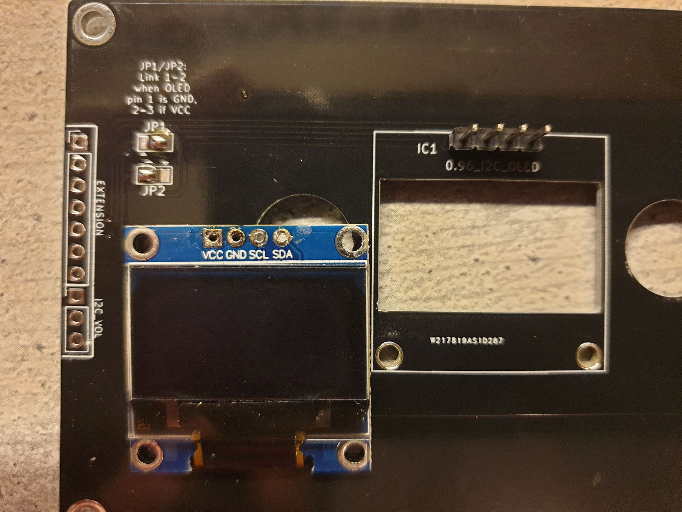
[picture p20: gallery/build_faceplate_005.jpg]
Jumpers and display


The way forward from here should be fairly straight-forward, but as hinted at earlier there is one important details that we need to deal with first. Simply put, there are even more variations of these displays floating around, but worse yet - the VCC and GND pins have been swapped around (effectively killing the display if we're not lucky enough to catch it in time). The way we handle it here is that, on the back of the faceplate there are two sets of solder jumpers that need to be made - JP1 and JP2. These need to be shorted according to the order of pins used on the OLED-display, solder accross *1-2* if the first one is marked **GND**. Pins *2-3* if it is marked **VCC**. With the display shown above, I needed to solder both across pins *2-3* (the little triangle denotes pin 1).

To solder it into place, just put the screen face down so that it is visible through the window in the PCB and solder it into place. Use M2 nylon screws and nuts to affix the bottom, this keeps people from accidentally pushing the display into the case though you need to be careful not to overtighten these - doing so will easily crack the glass. 

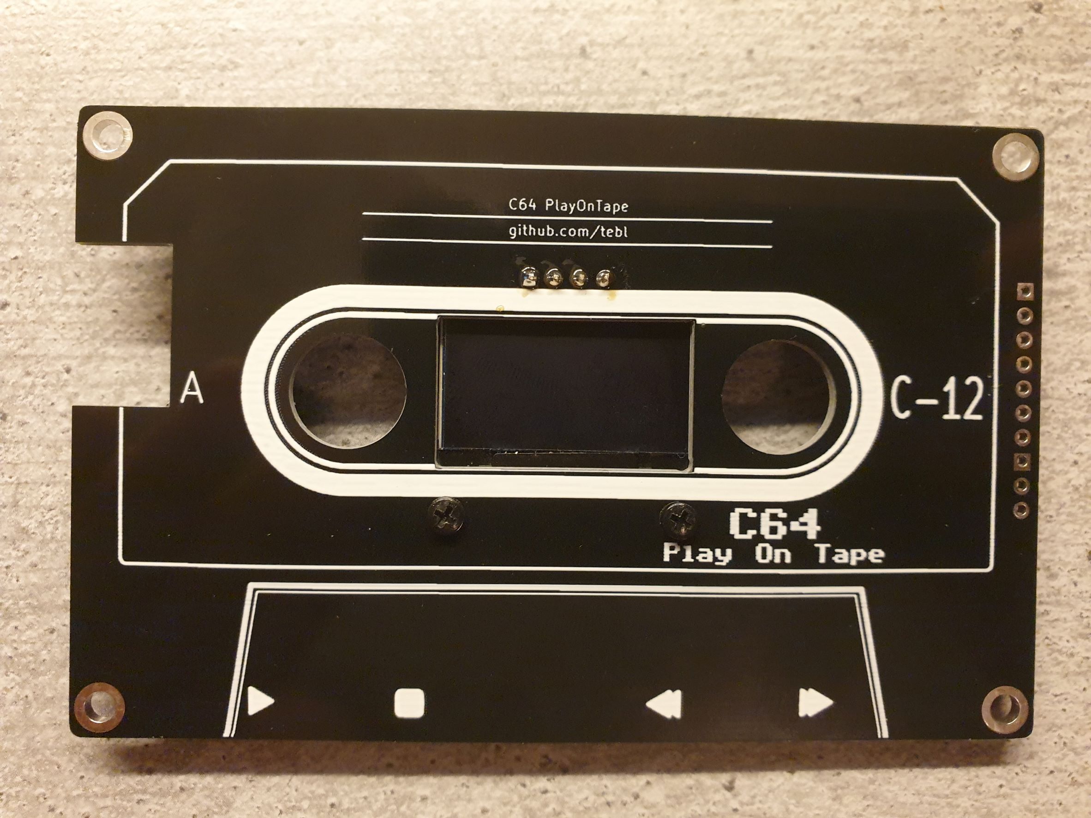
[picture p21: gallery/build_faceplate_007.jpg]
Faceplate with display


As the last step, solder into place the female pin headers on the underside of the faceplate, preferably with the faceplate installed on the main module with the required standoffs between the two - this ensures a good mechanical connection between the them. Theoretically you could install extra long pin headers here and solder it directly to the module under, but that is only recommended when building several units at once and components being used have been verified as being of good quality.

# 2> Schematic
The supplied KiCad files should be sufficient as both a schematic and as a  starting point for ordering PCBs (basically you could just zip the contents of the export folder and upload that on a fabrication site), the schematic is also available in [PDF-format](https://github.com/tebl/C64-PlayOnTape/tree/main/documentation/schematic) found within the schematics-part of the [documentation](https://github.com/tebl/C64-PlayOnTape/tree/main/documentation).

# 3> BOM
Most parts should be easy to get a hold of from your favourite local electronic component shop, but given that I don't have access to such shops where I live so everything was based on whatever I could get cheapest from eBay/AliExpress (free shipping, plan on waiting 3-4 weeks for delivery though).

| Reference | Item | Count |
| --- | --- | ----- |
| PCB | Fabricate using Gerber files | (1)|
| IC1 | SSD1306 I2C OLED 128x64 (0.96") (**"original"**) | (1)|
| J1 * | Female 3 pin header | 1 |
| J3 * | Female 7 pin header | 1 |

*) J1 and J3 are placed right next to eachother, so you could just install a female 10 pin header here. That'll also reduce number of parts needed by one, if that matters.

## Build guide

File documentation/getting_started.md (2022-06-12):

# Getting started
Remember waiting around for what sometimes would feel like forever, just to get your favourite game loaded from your trusty datasette? Well, now you can now attempt to return to a slightly less irritating version of those good old days - loading games'll take just as long as they did back then, just without the need to fiddle with the azimuth setting. Based on the rather excellent [tapuino](https://github.com/sweetlilmre/tapuino) project, there's even an accompanying [blog](http://sweetlilmre.blogspot.com/search/label/Tapuino) that included instructions on how to build one all by yourself.

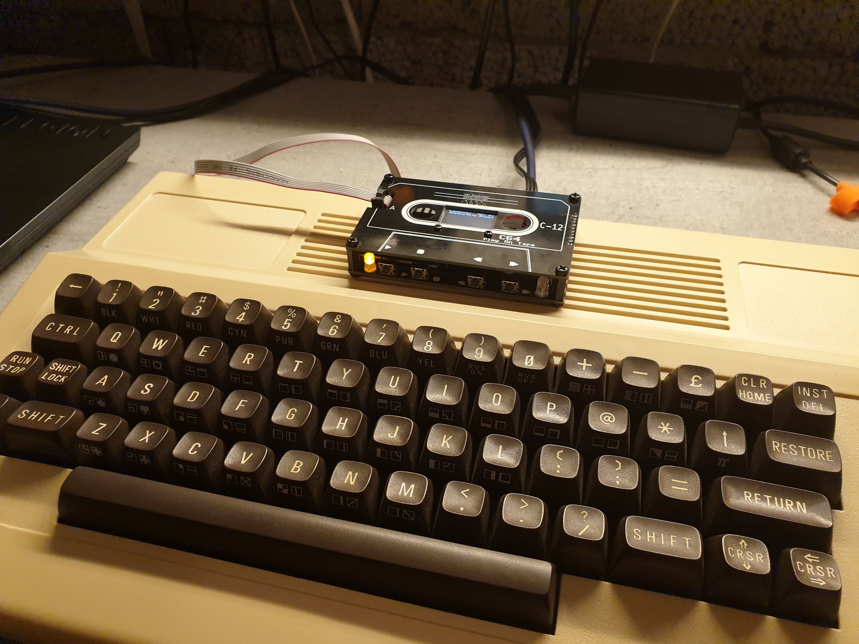
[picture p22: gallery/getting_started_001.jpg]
Getting started 001


A device such as the *tapuino* is in most ways, just the same as your trusty old Commodore Datasette (C2N), with one very notable difference - you'll be loading data from an SD-card instead of attempting to use your musty old tapes. From the viewpoint of your Commodore 64 it'll look just the same as the datasette, it's communicating over the same connector and the data will be barrelling down the cable at exactly the same rate (meaning that it'll take just as long to load as well). 

**NB!** These days it has become more and more common to have custom Commodore 64 kernals installed on your system, some of these dropped the tape-support in order to fit their own routines without requiring a larger of ROM chip. The moral of the story is that if something refuses to work, try it with the original ROM-chip in place.

# 1> Loading a game
There isn't really all that much that needs saying when it comes to loading games from tape, but what you'd need to do is enable *SHIFT LOCK*, push *RUN STOP* and then disable *SHIFT LOCK* again. At this point you would pick up your C64 PlayOnTape, browse to a TAP-file of your choice and then select it to start streaming the data to your computer. Check facebook, when the tape has finished loading you'll be able to play your game. That's all, folks! 

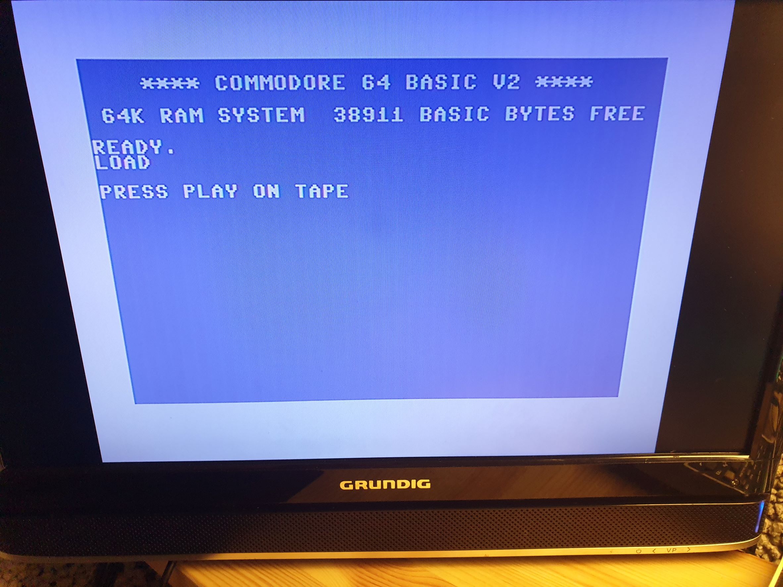
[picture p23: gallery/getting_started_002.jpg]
Getting started 002

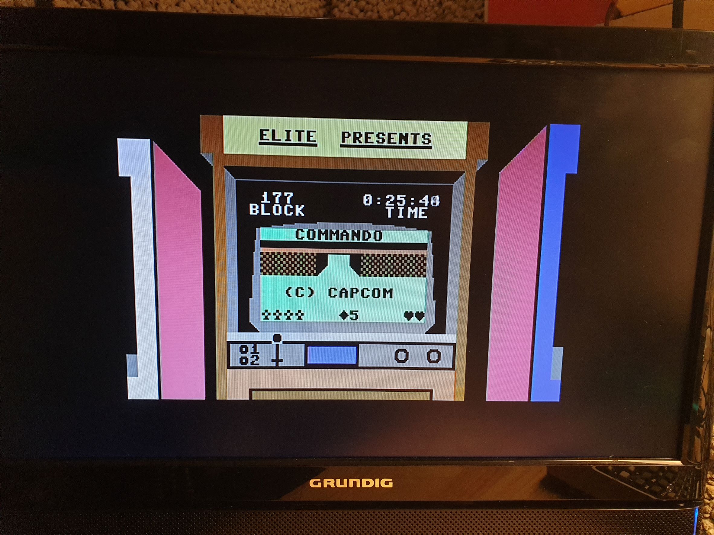
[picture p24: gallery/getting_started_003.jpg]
Getting started 002

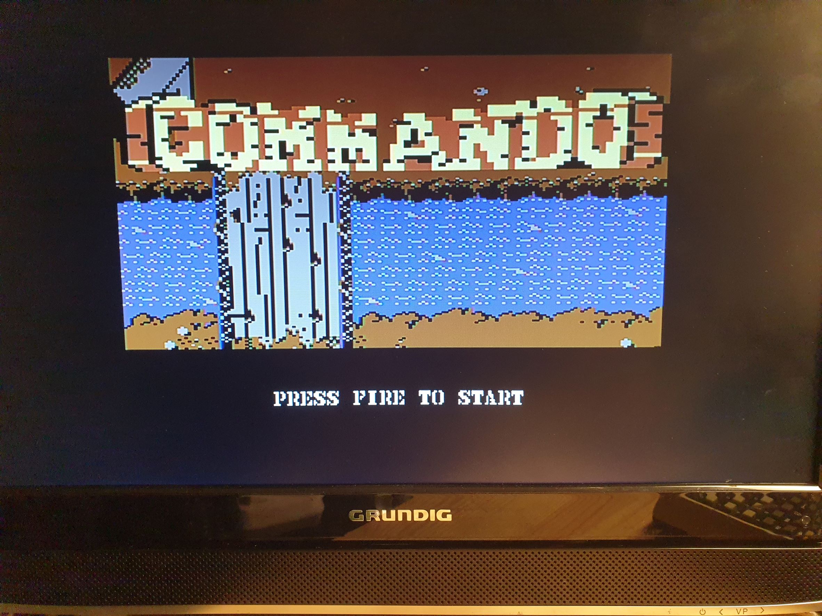
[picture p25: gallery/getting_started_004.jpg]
Getting started 002


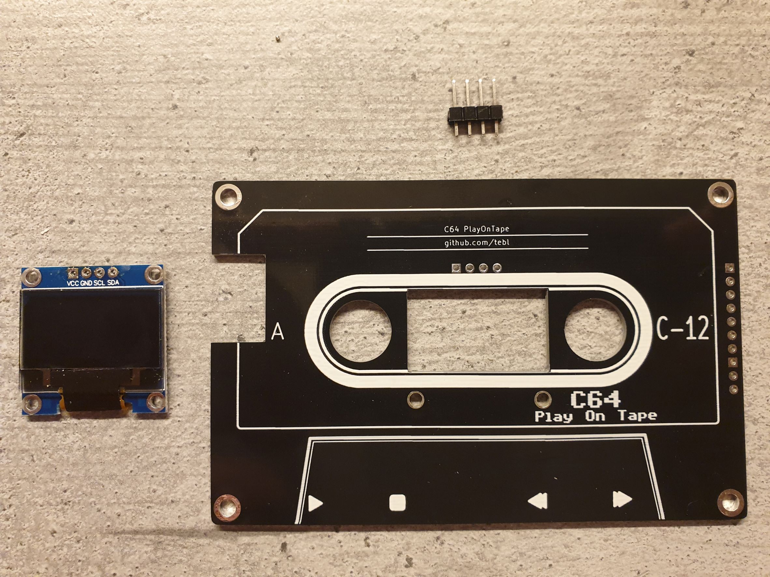
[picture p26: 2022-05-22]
gallery/build_faceplate_002.jpg

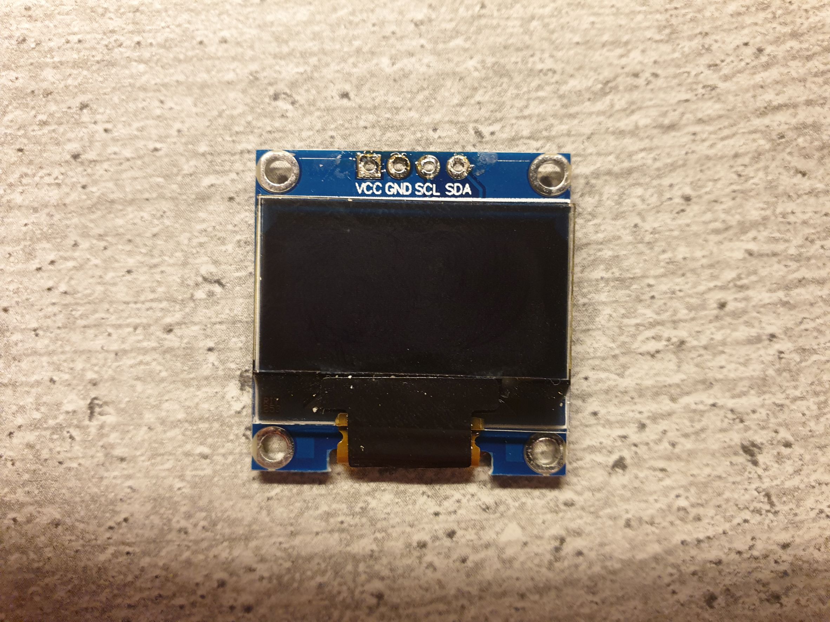
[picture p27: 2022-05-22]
gallery/build_faceplate_004.jpg

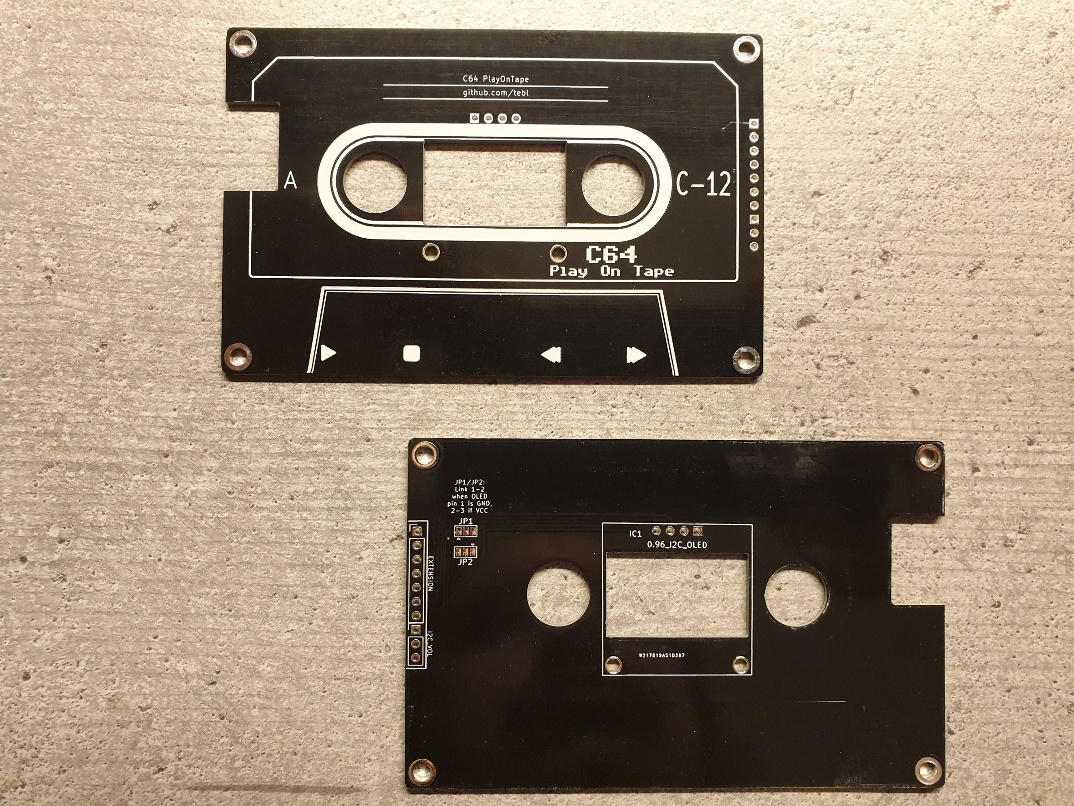
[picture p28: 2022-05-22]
gallery/build_faceplate_001.jpg

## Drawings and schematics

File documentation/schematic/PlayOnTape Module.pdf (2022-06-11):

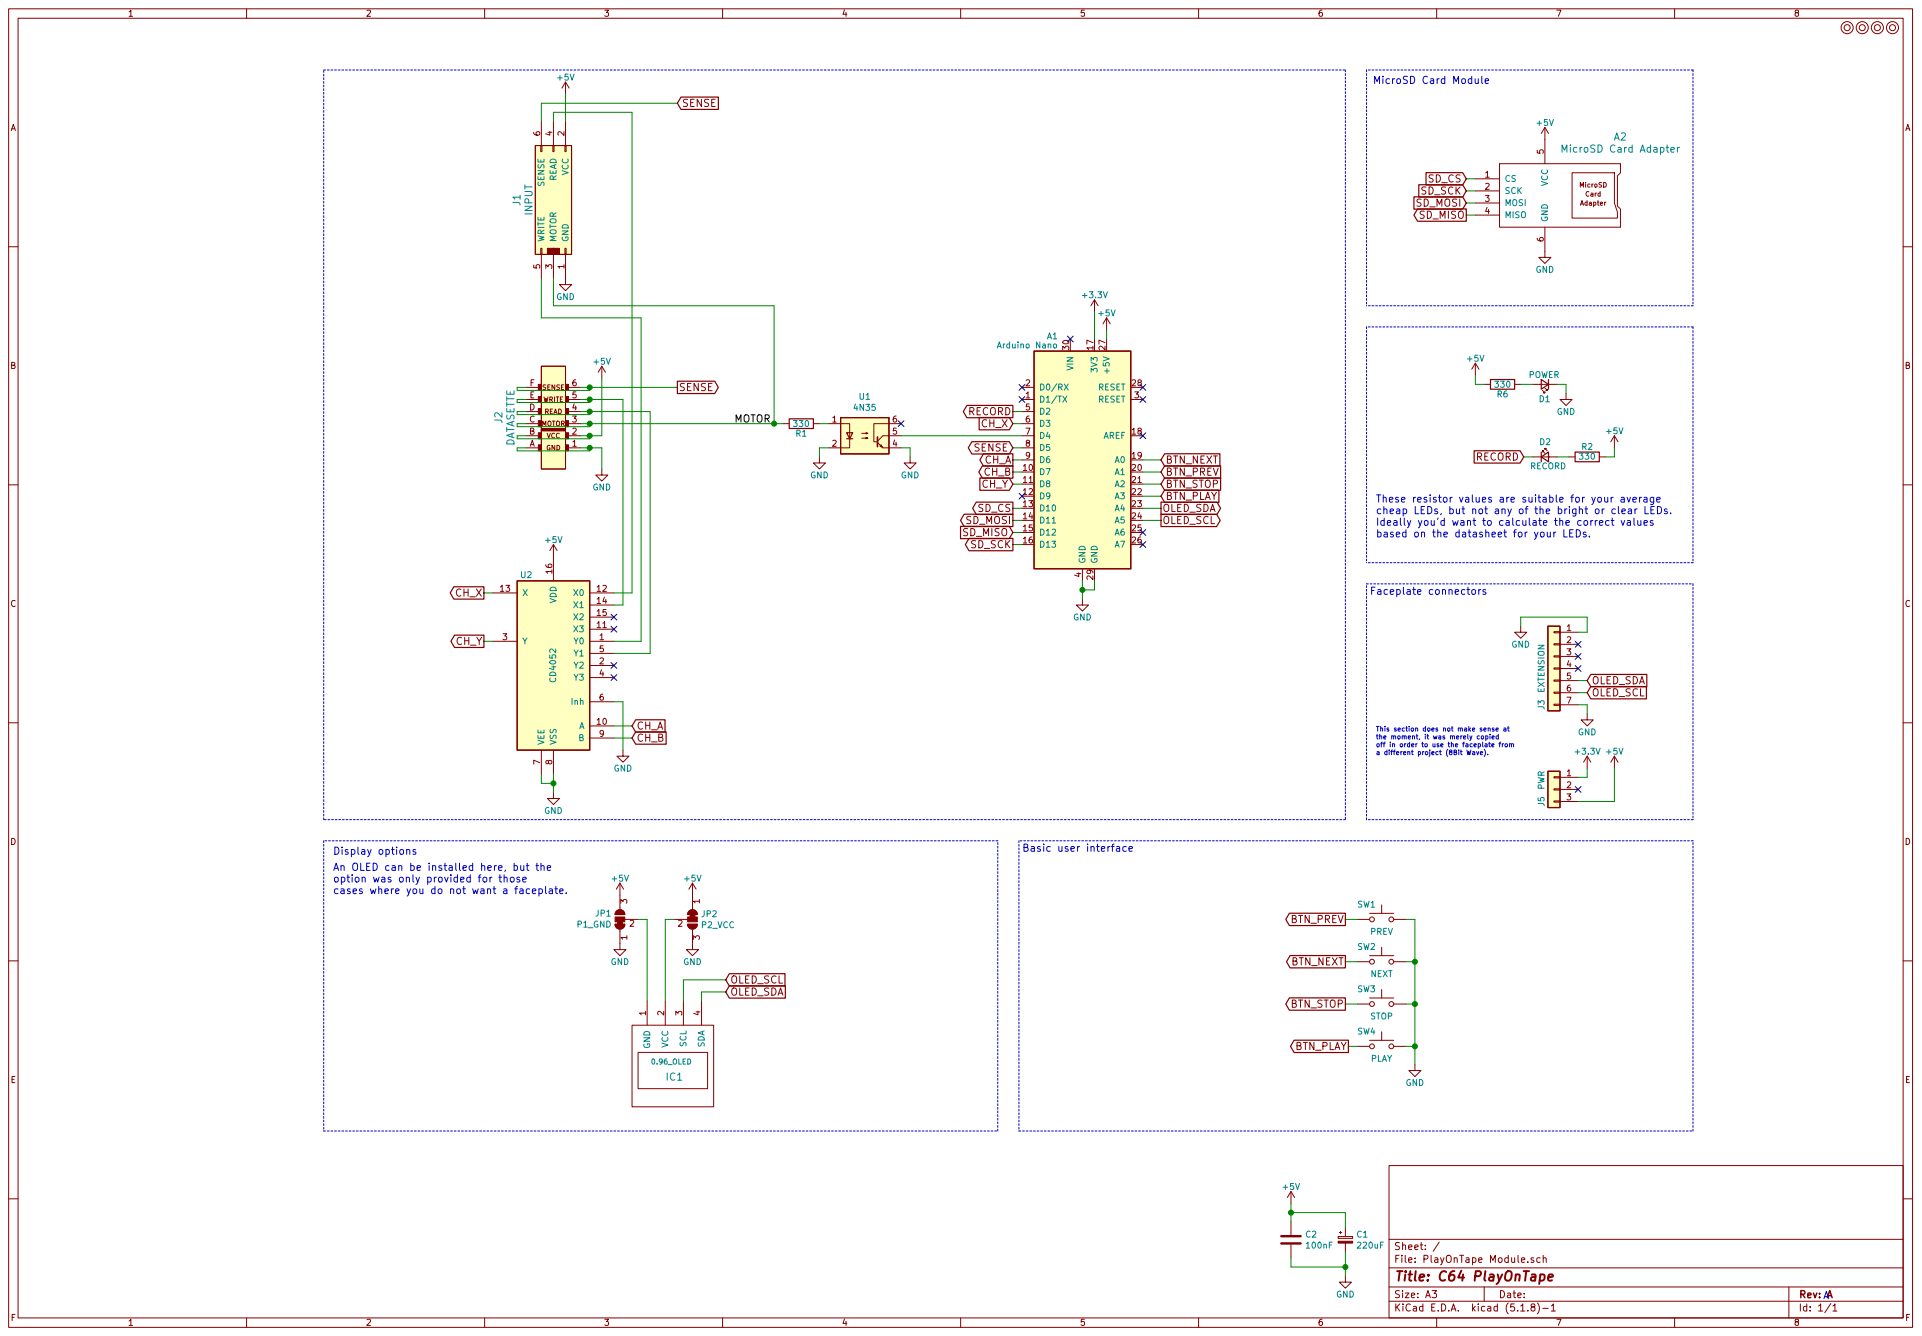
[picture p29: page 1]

330 GND 1 VCC 2 MOTOR 3 READ 4 WRITE 5 SENSE 6 J1 INPUT

These resistor values are suitable for your average
cheap LEDs, but not any of the bright or clear LEDs.
Ideally you'd want to calculate the correct values
based on the datasheet for your LEDs.

This section does not make sense at
the moment, it was merely copied
off in order to use the faceplate from

a different project (8Bit Wave). An OLED can be installed here, but the

option was only provided for those
cases where you do not want a faceplate.

File: PlayOnTape Module.sch Sheet: /

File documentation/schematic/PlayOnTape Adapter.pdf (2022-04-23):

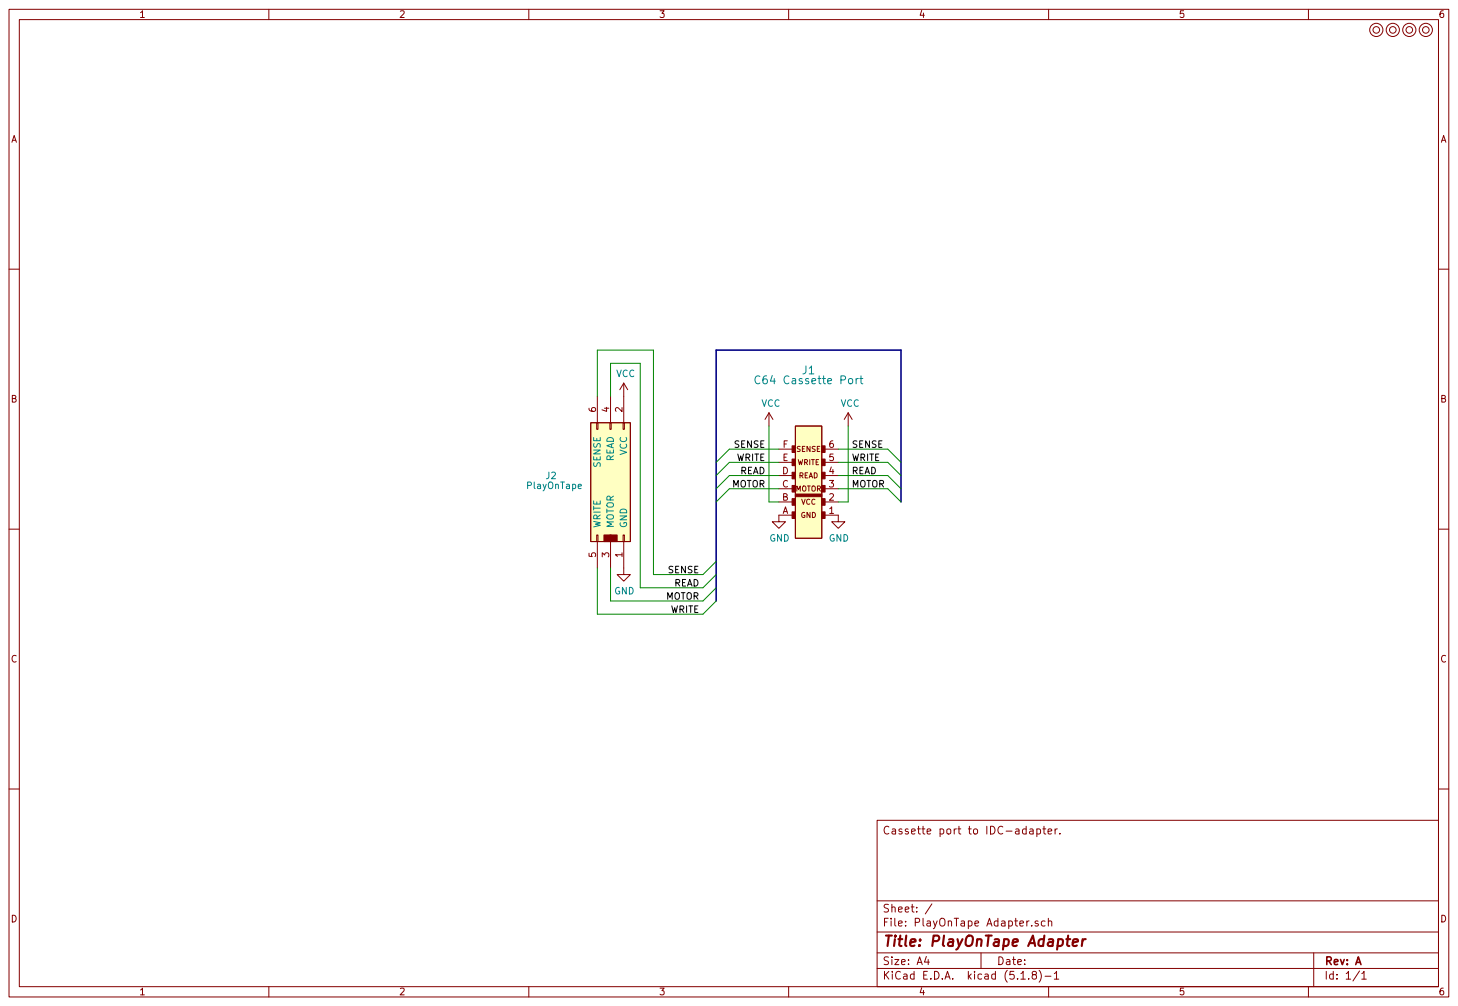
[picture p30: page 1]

File: PlayOnTape Adapter.sch Sheet: / Cassette port to IDC-adapter. GND

Id: 1/1 Title: PlayOnTape Adapter

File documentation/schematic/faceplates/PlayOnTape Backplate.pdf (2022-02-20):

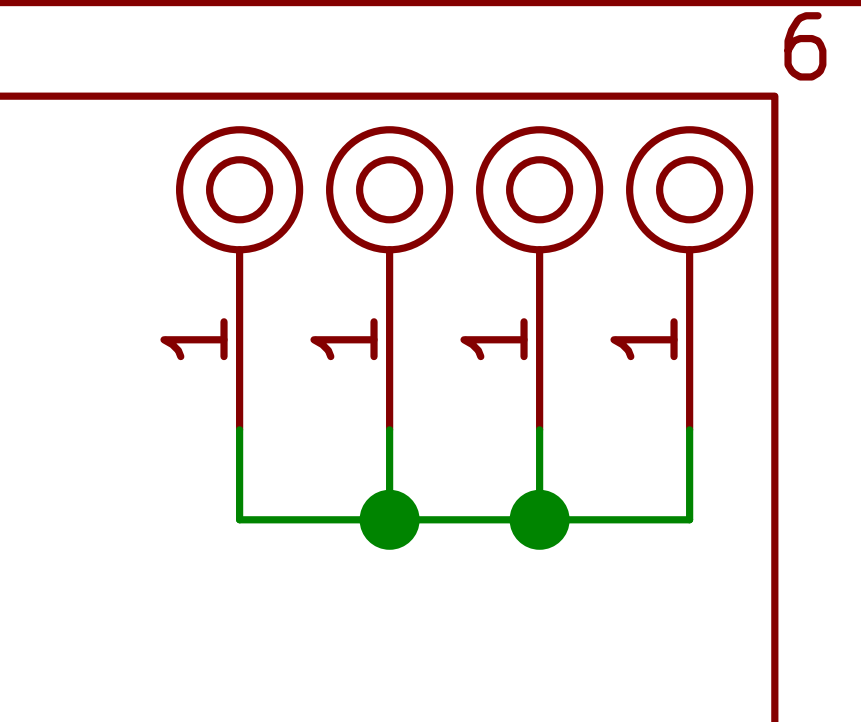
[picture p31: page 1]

This doesn't actually do anything,
it's just a pretty piece of PCB to go on the underside

File: PlayOnTape Backplate.sch Sheet: /
Id: 1/1 Title: PlayOnTape Backplate

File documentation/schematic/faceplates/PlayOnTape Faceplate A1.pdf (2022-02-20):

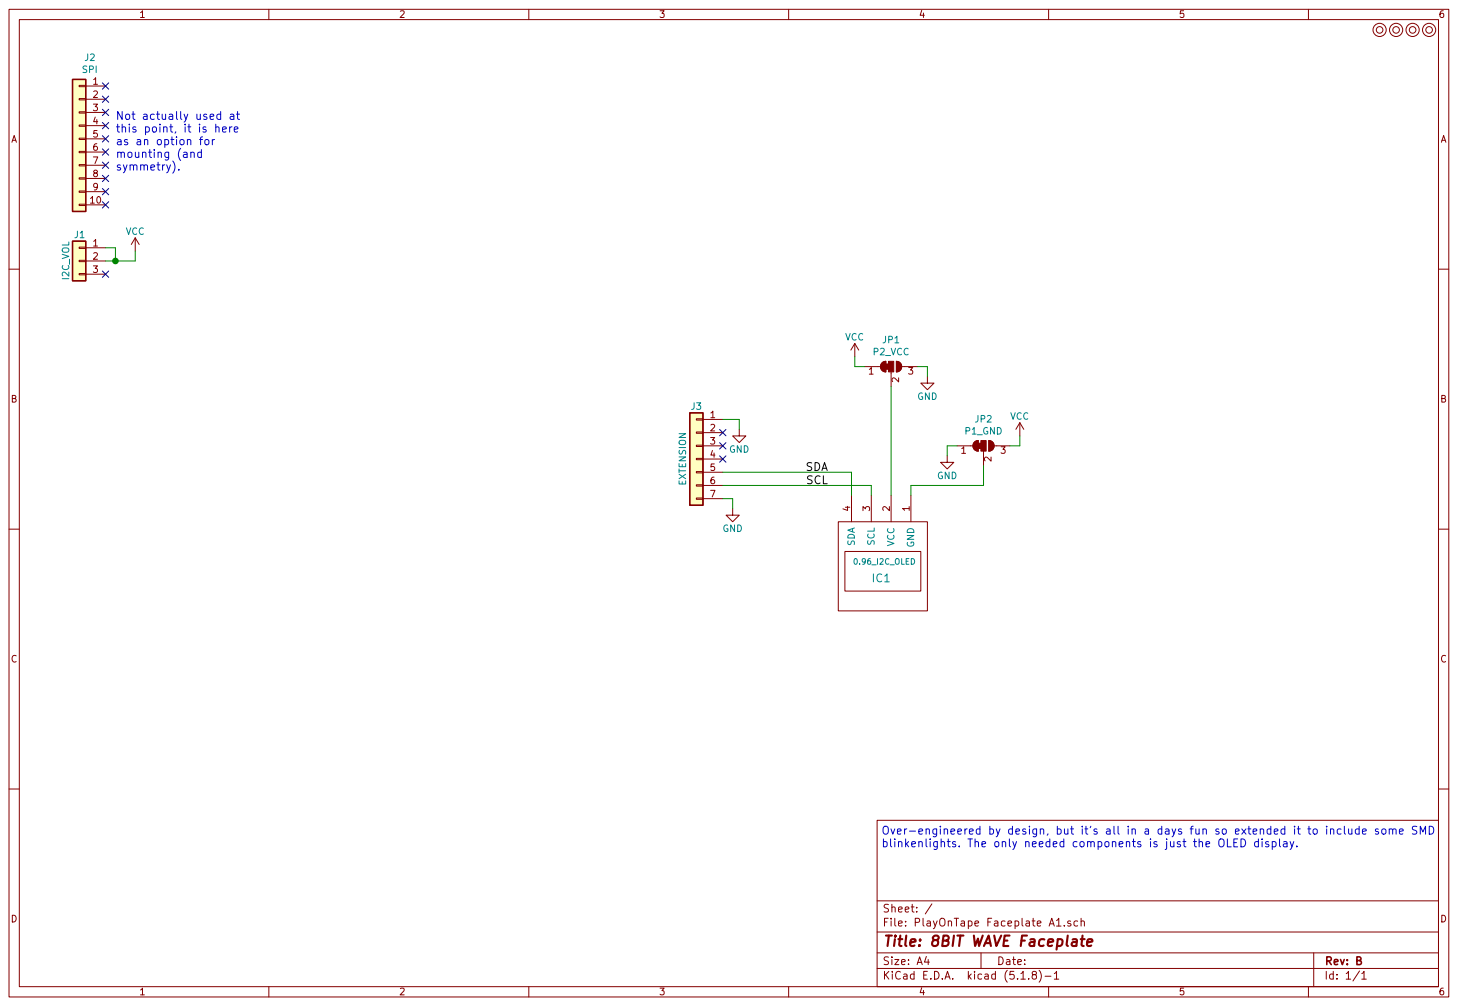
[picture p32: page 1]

Over-engineered by design, but it's all in a days fun so extended it to include some SMD
blinkenlights. The only needed components is just the OLED display.

File: PlayOnTape Faceplate A1.sch Sheet: /
Id: 1/1 Title: 8BIT WAVE Faceplate

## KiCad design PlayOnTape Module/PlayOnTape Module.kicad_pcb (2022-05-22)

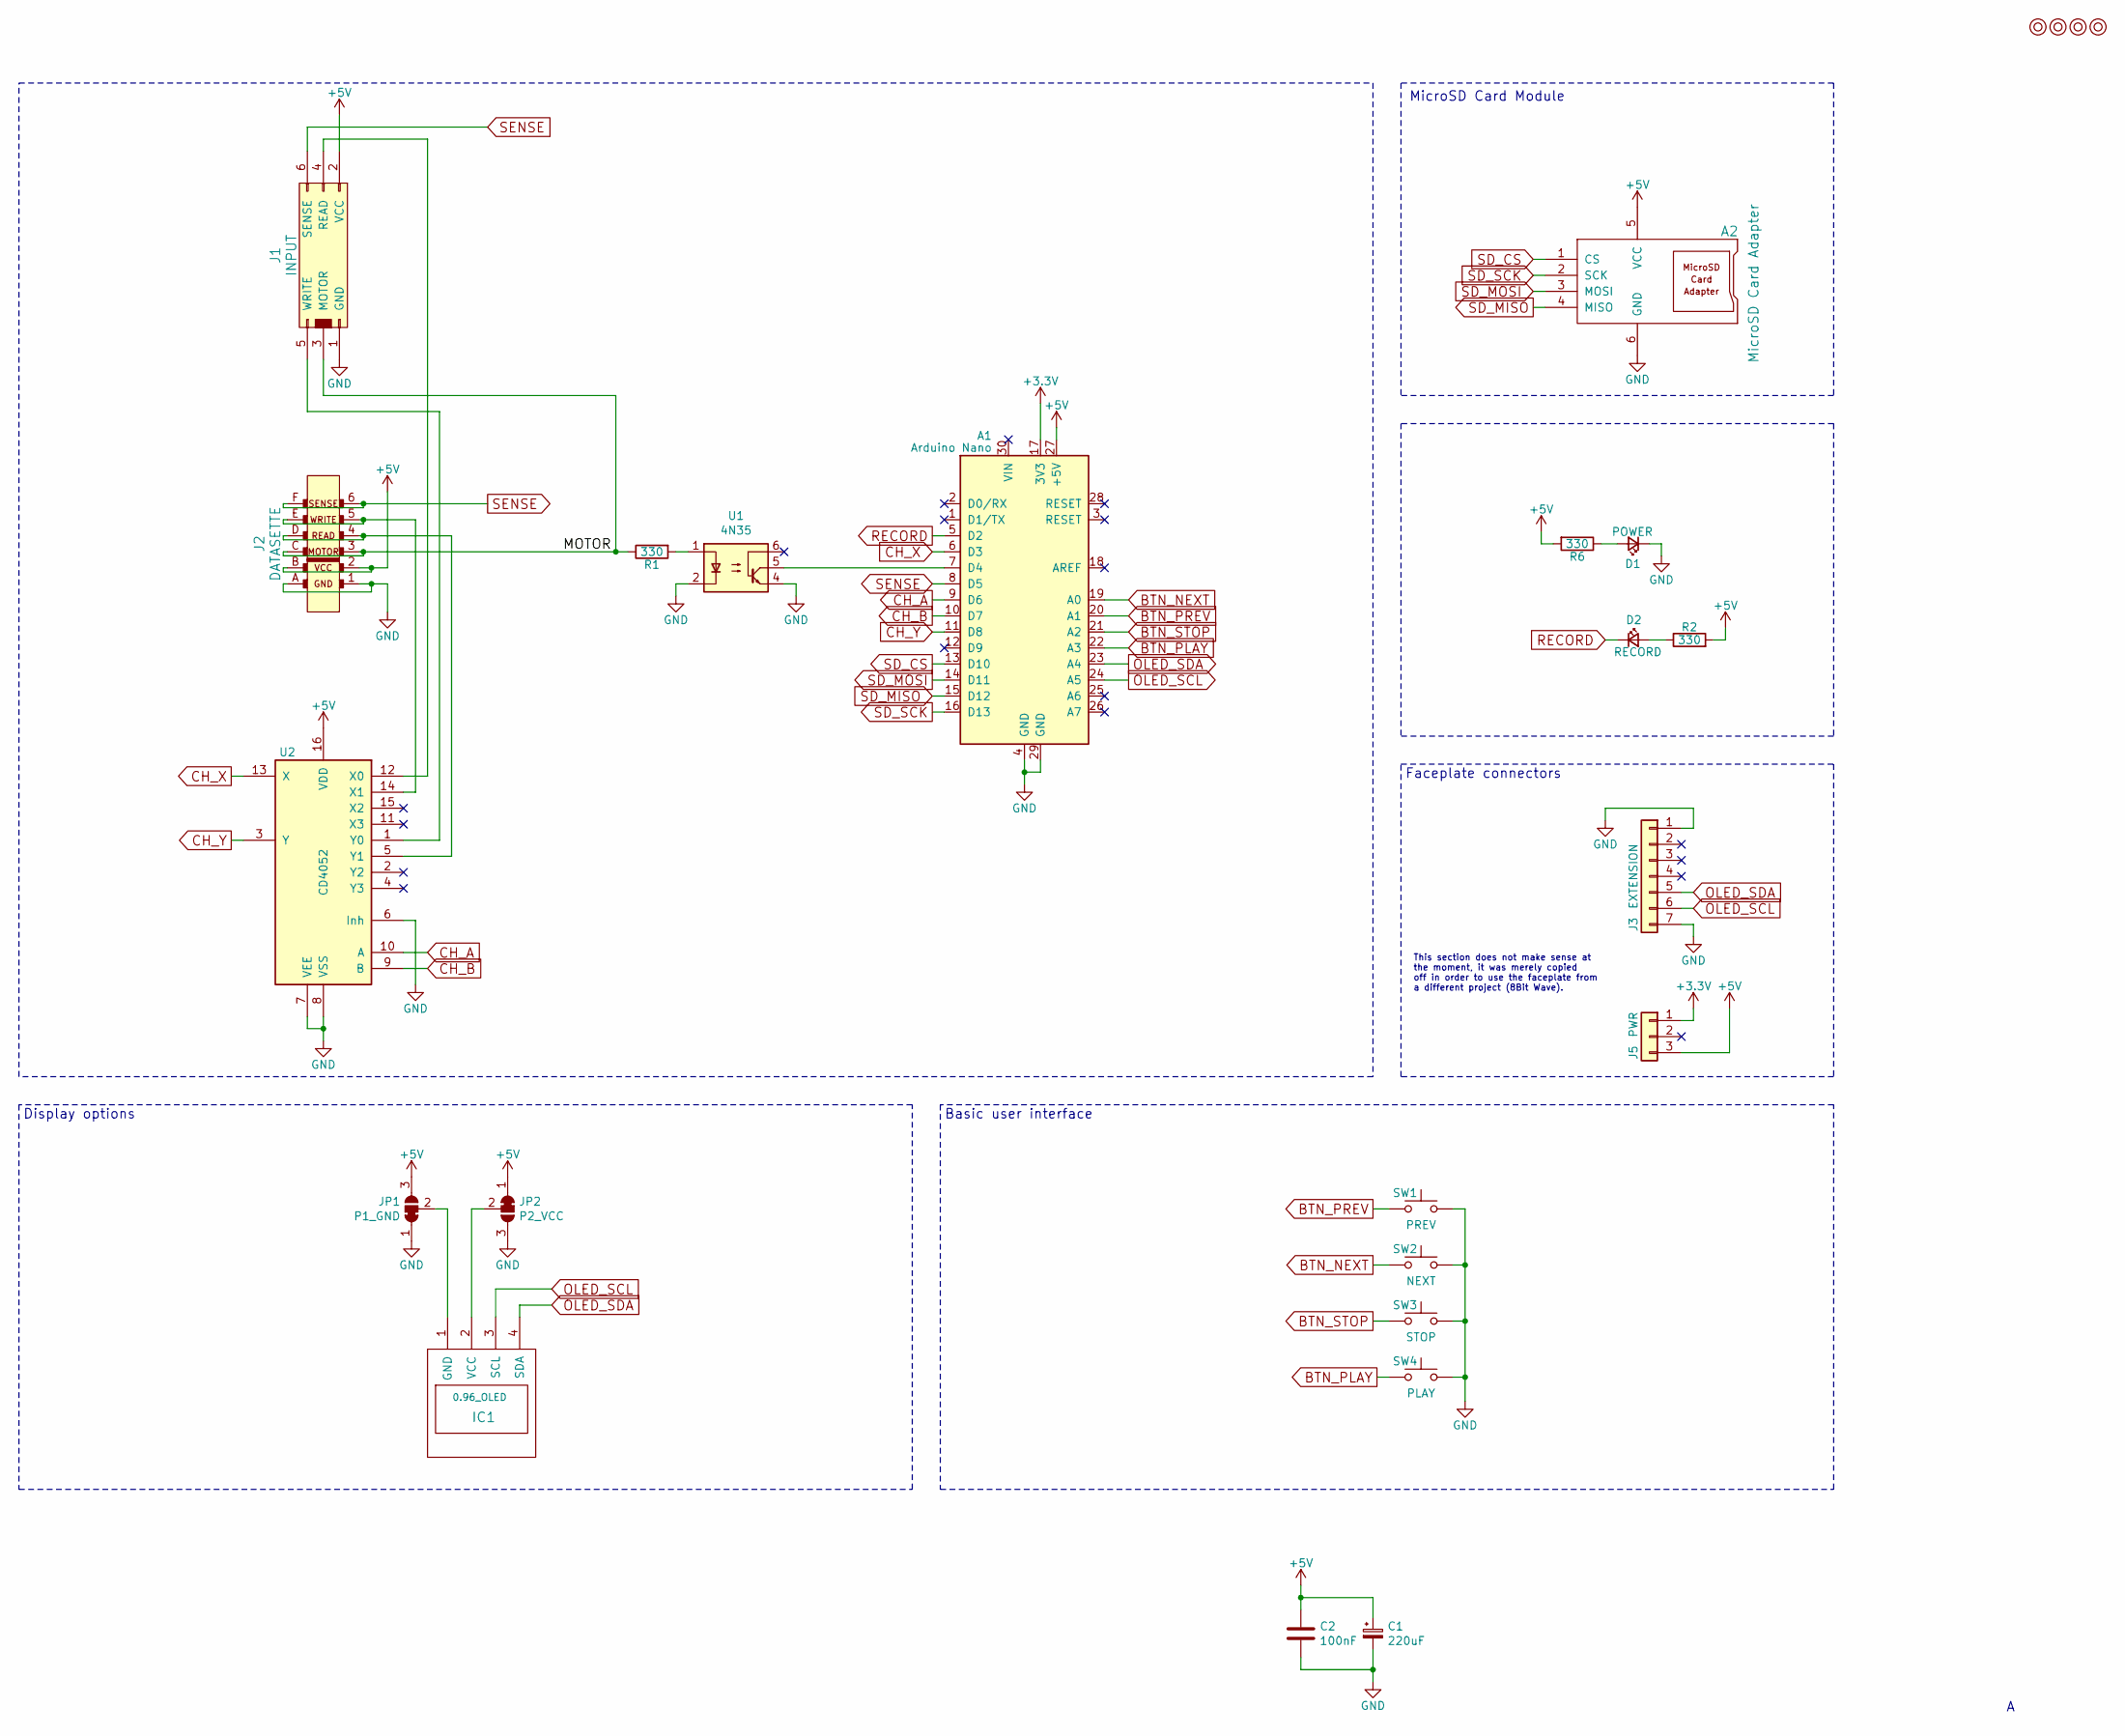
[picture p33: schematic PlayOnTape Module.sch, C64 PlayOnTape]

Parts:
A1: Arduino Nano; Arduino_Nano
A2: MicroSD Card Adapter; MicroSD_Card_Adapter
C1: 220uF; CP_Radial_D6.3mm_P2.50mm
C2: 100nF; C_Disc_D4.7mm_W2.5mm_P5.00mm
D1: POWER; LED_D5.0mm
D2: RECORD; LED_D5.0mm
IC1: 0.96_OLED; 0.96_I2C_OLED
J1: INPUT; IDC-Header_2x03_P2.54mm_Vertical
J2: DATASETTE; C64-Cassette-Port
J3: EXTENSION; Pin_Header_Straight_1x07_Pitch2.54mm
J5: PWR; PinHeader_1x03_P2.54mm_Vertical
JP1: P1_GND; SolderJumper-3_P1.3mm_Open_RoundedPad1.0x1.5mm
JP2: P2_VCC; SolderJumper-3_P1.3mm_Open_RoundedPad1.0x1.5mm
M1, M2, M3, M4: Mounting; M3
R1, R2, R6: 330; R_Axial_DIN0207_L6.3mm_D2.5mm_P10.16mm_Horizontal
SW1: PREV; SW_Tactile_SPST_Angled_PTS645Vx31-2LFS
SW2: NEXT; SW_Tactile_SPST_Angled_PTS645Vx31-2LFS
SW3: STOP; SW_Tactile_SPST_Angled_PTS645Vx31-2LFS
SW4: PLAY; SW_Tactile_SPST_Angled_PTS645Vx31-2LFS
U1: 4N35; DIP-6_W7.62mm_Socket_LongPads
U2: CD4052; DIP-16_W7.62mm_Socket_LongPads

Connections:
+3V3: A1.17 (3V3), J5.1
+5V: A1.27 (+5V), A2.5 (VCC), C1.1, C2.1, J1.2 (VCC), J2.2 (VCC), J2.B (VCC), J5.3, JP1.3 (B), JP2.1 (A), R2.2, R6.2, U2.16 (VDD)
/MOTOR: J1.3 (MOTOR), J2.3 (MOTOR), J2.C (MOTOR), R1.1
BTN_NEXT: A1.19 (A0), SW2.1
BTN_PLAY: A1.22 (A3), SW4.1
BTN_PREV: A1.20 (A1), SW1.1
BTN_STOP: A1.21 (A2), SW3.1
CH_A: A1.9 (D6), U2.10 (A)
CH_B: A1.10 (D7), U2.9 (B)
CH_X: A1.6 (D3), U2.13 (X)
CH_Y: A1.11 (D8), U2.3 (Y)
GND: A1.4 (GND), A1.29 (GND), A2.6 (GND), C1.2, C2.2, D1.1 (K), J1.1 (GND), J2.1 (GND), J2.A (GND), J3.1, J3.7, JP1.1 (A), JP2.3 (B), SW1.2, SW2.2, SW3.2, SW4.2, U1.2, U1.4, U2.6 (Inh), U2.7 (VEE), U2.8 (VSS)
unnamed: A1.7 (D4), U1.5
unnamed: D1.2 (A), R6.1
unnamed: D2.2 (A), R2.1
unnamed: IC1.1 (GND), JP1.2 (C)
unnamed: IC1.2 (VCC), JP2.2 (C)
unnamed: J1.4 (READ), U2.12 (X0)
unnamed: J1.5 (WRITE), U2.1 (Y0)
unnamed: J2.4 (READ), J2.D (EREAD), U2.5 (Y1)
unnamed: J2.5 (WRITE), J2.E (WRITE), U2.14 (X1)
unnamed: R1.2, U1.1
OLED_SCL: A1.24 (A5), IC1.3 (SCL), J3.6
OLED_SDA: A1.23 (A4), IC1.4 (SDA), J3.5
RECORD: A1.5 (D2), D2.1 (K)
SD_CS: A1.13 (D10), A2.1 (CS)
SD_MISO: A1.15 (D12), A2.4 (MISO)
SD_MOSI: A1.14 (D11), A2.3 (MOSI)
SD_SCK: A1.16 (D13), A2.2 (SCK)
SENSE: A1.8 (D5), J1.6 (SENSE), J2.6 (SENSE), J2.F (SENSE)

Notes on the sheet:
Faceplate connectors
This section does not make sense at the moment, it was merely copied off in order to use the faceplate from a different project (8Bit Wave).
Basic user interface
Display options
MicroSD Card Module

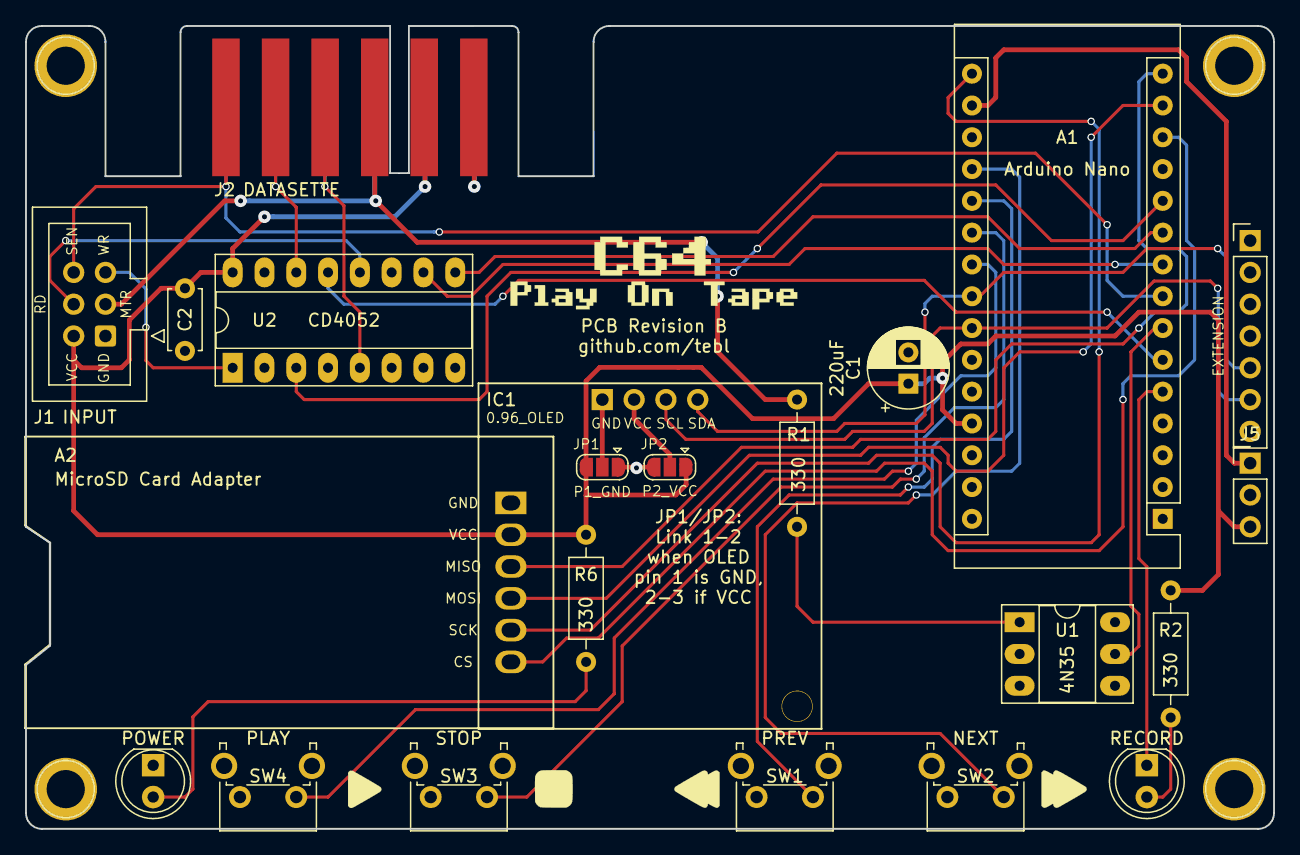
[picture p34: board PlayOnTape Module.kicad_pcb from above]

Board: 2 copper layers, 99.7 x 64.1 mm, 26 parts (0 on the bottom side), 30 nets.

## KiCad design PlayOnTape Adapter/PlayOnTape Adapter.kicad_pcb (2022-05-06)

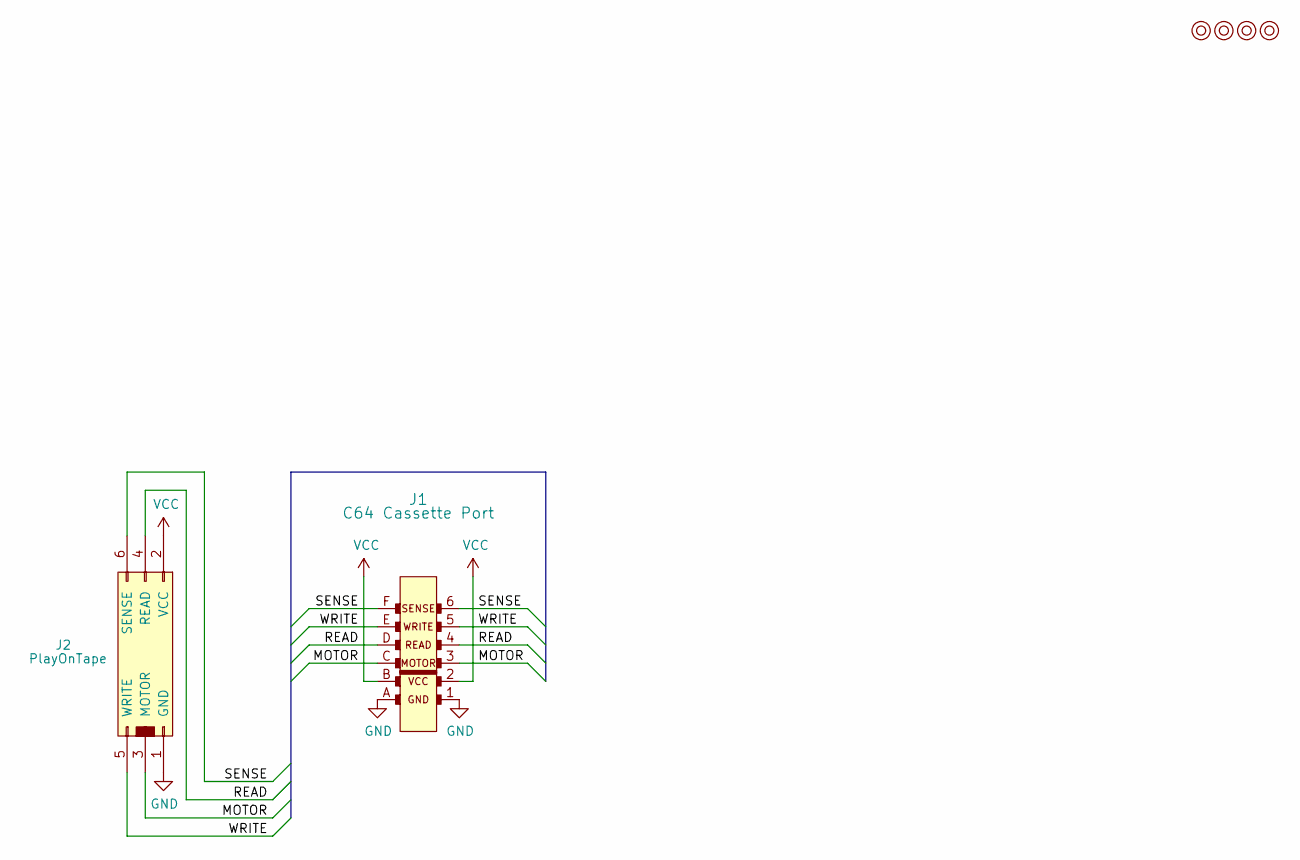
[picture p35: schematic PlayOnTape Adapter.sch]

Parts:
J1: C64 Cassette Port; C64_Cassette-Edge
J2: PlayOnTape; IDC-Header_2x03_P2.54mm_Vertical
M1, M2, M3, M4: Mounting; M3_pin

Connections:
/MOTOR: J1.3 (MOTOR), J1.C (MOTOR), J2.3 (MOTOR)
/READ: J1.4 (READ), J1.D (EREAD), J2.4 (READ)
/SENSE: J1.6 (SENSE), J1.F (SENSE), J2.6 (SENSE)
/WRITE: J1.5 (WRITE), J1.E (WRITE), J2.5 (WRITE)
GND: J1.1 (GND), J1.A (GND), J2.1 (GND)
VCC: J1.2 (VCC), J1.B (VCC), J2.2 (VCC)

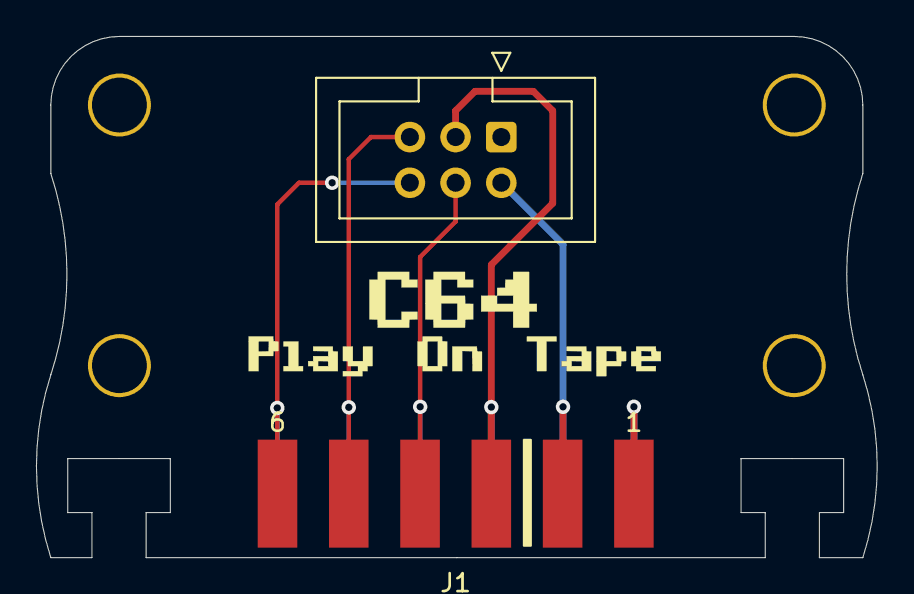
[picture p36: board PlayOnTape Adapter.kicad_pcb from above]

Board: 2 copper layers, 46.7 x 29.0 mm, 6 parts (0 on the bottom side), 6 nets.

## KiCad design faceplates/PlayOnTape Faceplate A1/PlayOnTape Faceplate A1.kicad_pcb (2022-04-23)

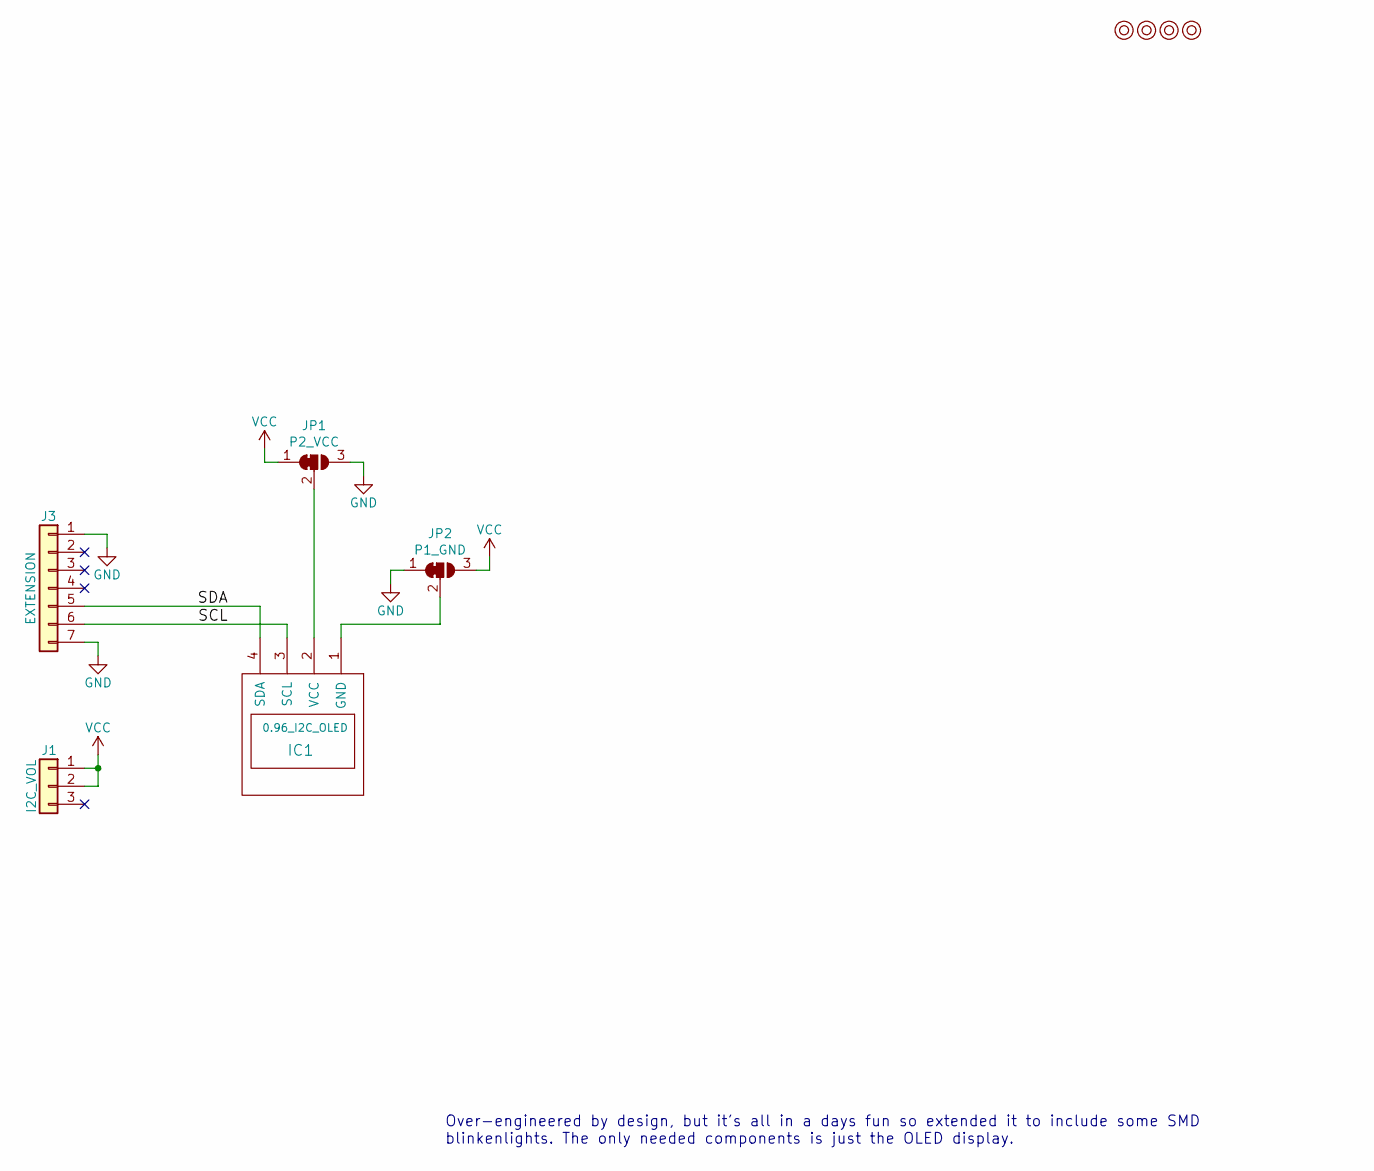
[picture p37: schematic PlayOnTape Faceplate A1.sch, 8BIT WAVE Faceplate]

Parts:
IC1: 0.96_I2C_OLED; 0.96_I2C_OLED2
J1: I2C_VOL; Pin_Header_Straight_1x03_Pitch2.54mm
J3: EXTENSION; Pin_Header_Straight_1x07_Pitch2.54mm
JP1: P2_VCC; SolderJumper-3_P1.3mm_Open_Pad1.0x1.5mm
JP2: P1_GND; SolderJumper-3_P1.3mm_Open_Pad1.0x1.5mm
M1, M2, M3, M4: Mounting; M3

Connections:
/SCL: IC1.3 (SCL), J3.6
/SDA: IC1.4 (SDA), J3.5
GND: J3.1, J3.7, JP1.3 (B), JP2.1 (A)
unnamed: IC1.1 (GND), JP2.2 (C)
unnamed: IC1.2 (VCC), JP1.2 (C)
VCC: J1.1, J1.2, JP1.1 (A), JP2.3 (B)

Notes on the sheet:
Over-engineered by design, but it's all in a days fun so extended it to include some SMD blinkenlights. The only needed components is just the OLED display.

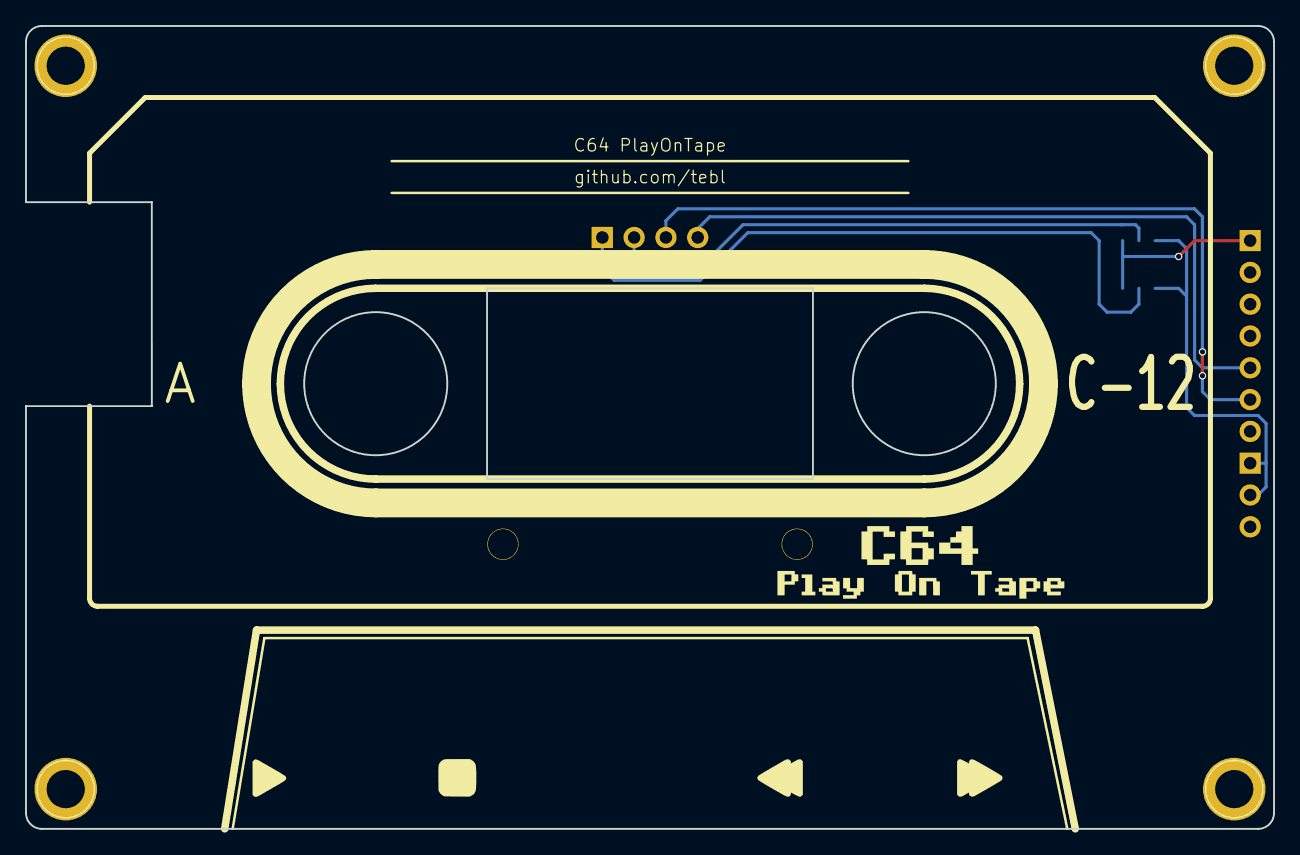
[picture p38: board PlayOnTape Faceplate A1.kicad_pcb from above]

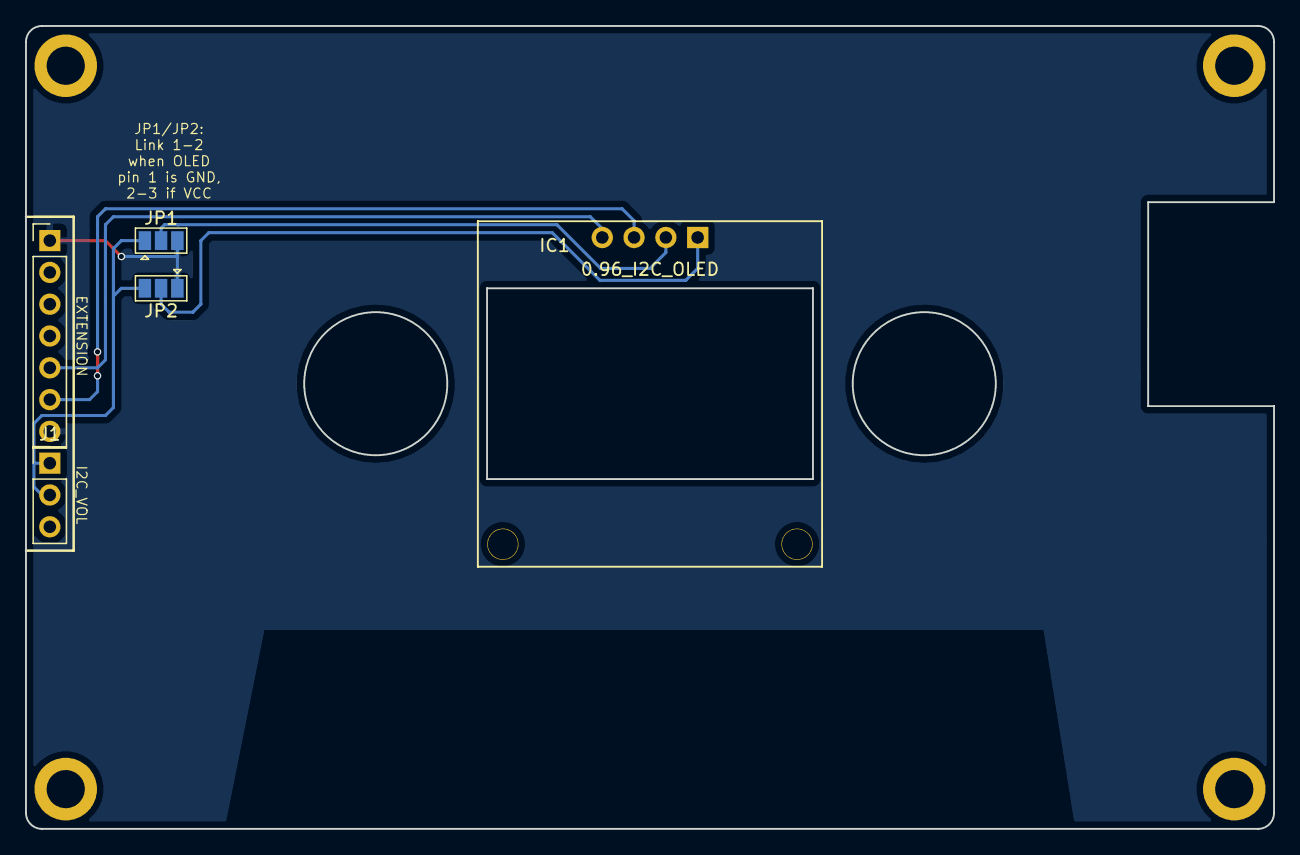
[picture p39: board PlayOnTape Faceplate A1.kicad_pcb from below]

Board: 2 copper layers, 99.7 x 64.1 mm, 9 parts (4 on the bottom side), 6 nets.

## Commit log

2022-01-29 Rough component placement
    [PlayOnTape Module.kicad_pcb, PlayOnTape Module.sch]
2022-01-29 Gerber export
    [PlayOnTape Module-B_Cu.gbl, PlayOnTape Module-B_Mask.gbs, PlayOnTape Module-B_Paste.gbp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]
2022-01-29 Beginning of README
    [PlayOnTape Module.kicad_pcb]
2022-02-19 Move C1
    [PlayOnTape Module.kicad_pcb]
2022-02-19 Enlarge SD adapter holes
    [PlayOnTape Module.kicad_pcb]
2022-02-20 Add backplate
    [PlayOnTape Backplate-B_Cu.gbl, PlayOnTape Backplate-B_Mask.gbs, PlayOnTape Backplate-B_Paste.gbp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]
2022-02-20 Faceplate A1 added
    [PlayOnTape Faceplate A1-B_Cu.gbl, PlayOnTape Faceplate A1-B_Mask.gbs, PlayOnTape Faceplate A1-B_Paste.gbp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]
2022-02-20 Tweak input mounting holes
    [PlayOnTape Module-B_Cu.gbl, PlayOnTape Module-B_Mask.gbs, PlayOnTape Module-B_Paste.gbp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]
2022-02-20 Reroute some tracks
    [PlayOnTape Faceplate A1-B_Cu.gbl, PlayOnTape Faceplate A1-B_Mask.gbs, PlayOnTape Faceplate A1-B_Paste.gbp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]
2022-04-22 Fixed OLED jumpers
    [PlayOnTape Faceplate A1.kicad_pcb, PlayOnTape Faceplate A1.sch, PlayOnTape Module.kicad_pcb]
2022-04-23 Changed to use IDC cable
    [PlayOnTape Adapter.kicad_pcb, PlayOnTape Adapter.sch, PlayOnTape Faceplate A1.kicad_pcb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]
2022-04-23 Remove old temporary files
    [PlayOnTape Module-B_Cu.gbl, PlayOnTape Module-B_Mask.gbs, PlayOnTape Module-B_Paste.gbp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]
2022-04-23 Add schematic
2022-04-23 Update schematic
2022-04-23 Remove temporary files
    [PlayOnTape Backplate-B_Cu.gbl, PlayOnTape Backplate-B_Mask.gbs, PlayOnTape Backplate-B_Paste.gbp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]
2022-04-23 Add connector cutout
    [PlayOnTape Faceplate A1.kicad_pcb, PlayOnTape Faceplate A1.sch, PlayOnTape Module.kicad_pcb]
2022-05-22 Silkscreen tweaks
    [PlayOnTape Module.kicad_pcb]
2022-06-11 Some build instructions added
    [PlayOnTape Module.sch]
2022-06-12 Added BOM

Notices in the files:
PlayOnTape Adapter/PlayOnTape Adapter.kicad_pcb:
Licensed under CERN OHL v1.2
